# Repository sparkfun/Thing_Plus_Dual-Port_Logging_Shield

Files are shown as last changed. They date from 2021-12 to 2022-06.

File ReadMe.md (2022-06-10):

SparkFun Thing Plus Dual-Port Logging Shield
========================================

SparkFun Thing Plus Dual-Port Logging Shield (DEV-19217) (https://www.sparkfun.com/products/19217)

[*SparkFun Thing Plus Dual-Port Logging Shield (DEV-19217)*](https://www.sparkfun.com/products/19217)

The SparkFun Thing Plus Dual-Port Logging Shield is a Thing Plus/Feather compatible board that allows you to access your microSD card over **_both_** SPI and USB-C! It is designed to be mounted on or under one of our [Thing Plus boards](https://www.sparkfun.com/thing_plus). You can log data to and read data from your microSD card over SPI as usual, using your favorite Arduino SD library. But you can also connect it to your computer via USB-C and read and write files at **_up to 35 MBytes/second_**! The write speed is card-dependent but, in our tests, we've routinely seen write speeds around 20MB/s.

Repository Contents
-------------------

* **/Documents** - Data sheets, additional product information
* **/Firmware/Dual-Port_microSD_Shield** - Firmware for the ATtiny 
* **/Hardware** - Eagle design files (.brd, .sch)
* **/img** - Final production files.

Documentation
--------------
* **[Library](https://github.com/sparkfun/SparkFun_Dual-Port_Logging_Shield_Arduino_Library)** - Arduino library for the SparkFun Thing Plus Dual-Port Logging Shield.
* **[Hookup Guide](https://learn.sparkfun.com/tutorials/thing-plus-dual-port-logging-shield-hookup-guide)** - Basic hookup guide for the SparkFun Thing Plus Dual-Port Logging Shield.

License Information
-------------------

This product is _**open source**_! 

Please review the LICENSE.md file for license information. 

If you have any questions or concerns on licensing, please contact technical support on our [SparkFun forums](https://forum.sparkfun.com/viewforum.php?f=152).

Distributed as-is; no warranty is given.

- Your friends at SparkFun.

_<COLLABORATION CREDIT>_

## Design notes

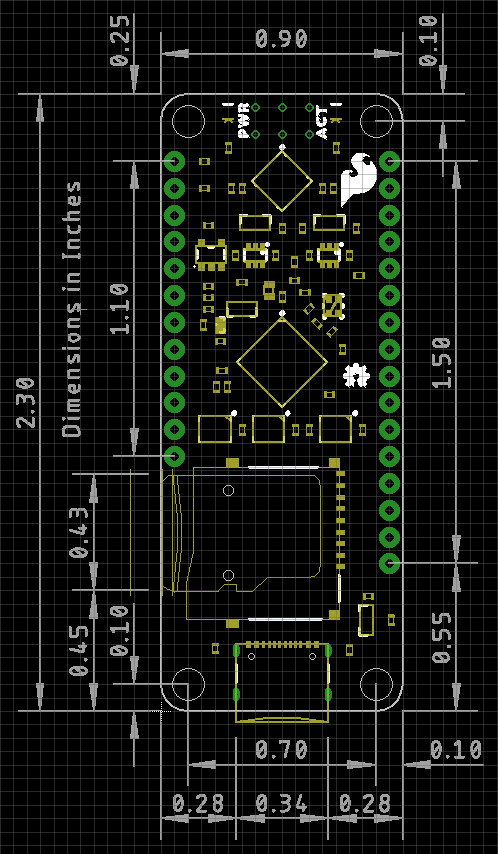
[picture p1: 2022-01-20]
img/Dimensions.png

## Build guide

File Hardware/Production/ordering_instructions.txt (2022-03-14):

panel size, 131x201mm
PCB thickness, 1.6mm
number of layers, 4
soldermask color, Red
silkscreen color, White
oz copper, 1oz
finish, HASL lead free
stencils, top
pcs per panel, 15
min trace width, 0.1524mm / 0.0060in
min drill size, 0.3000mm / 0.0118in
filename to layer stackup 1/2/3/4: GTL, GL2, GL3, GBL

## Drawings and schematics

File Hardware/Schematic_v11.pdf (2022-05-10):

Design by: USB⁻C S | D G S | D G | DS G | D | S G | D | S G

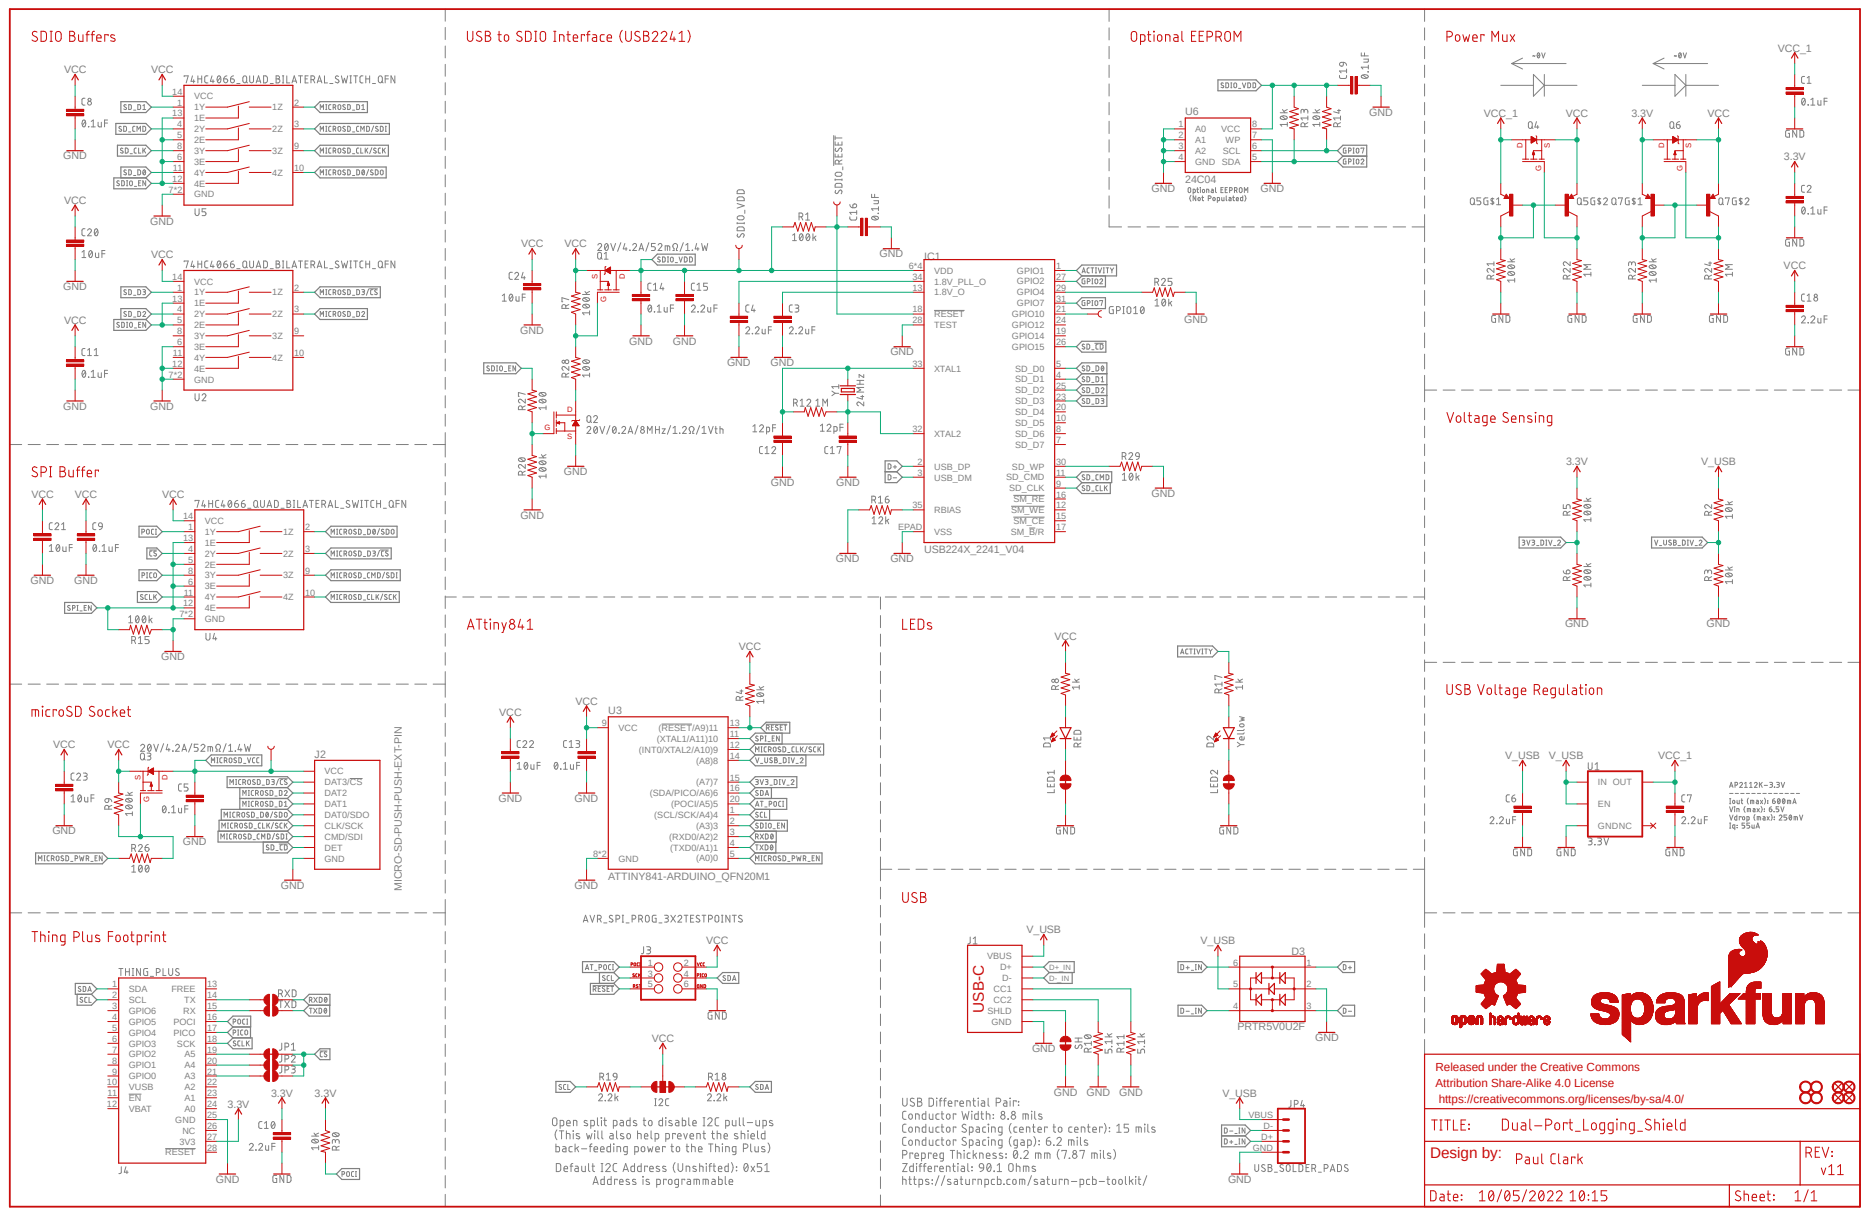
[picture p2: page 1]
GND; GND GND; V_USB; GND MICRO⁻SD⁻PUSH⁻PUSH⁻EXT⁻PIN; ATTINY841-ARDUINO_QFN20M1 GND; V_USB V_USB; VCC; VCC_1; USB224X_2241_V04; PRTR5V0U2F; VBUS CC1 D+D- CC2 SHLD; VCC 9; (A3)3 2 (RXD0/A2)2 3 (TXD0/A1)1 4 (A0)0 5; (SCL/SCK/A4)4 1; (XTAL1/A11)10 11 (INT0/XTAL2/A10)9 12 (A8)8 14; (RESET/A9)11 13 GND 8*2U3; 4Z 10 VCC 14 GND 7*2; 6 SDA 1 SCL 2 GPIO6 3 GPIO5 4 GPIO4 5 GPIO3 6 GPIO2 7 GPIO1 8 GPIO0 9 VUSB 10 EN 11 VBAT 12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

DAT2 DAT1 CLK/SCK DET VCC
DAT3/CS CMD/SDI DAT0/SDO

(POCI/A5)5 20 (SDA/PICO/A6)6 16 (A7)7 15

Released under the Creative Commons
Attribution Share-Alike 4.0 License
https://creativecommons.org/licenses/by-sa/4.0/

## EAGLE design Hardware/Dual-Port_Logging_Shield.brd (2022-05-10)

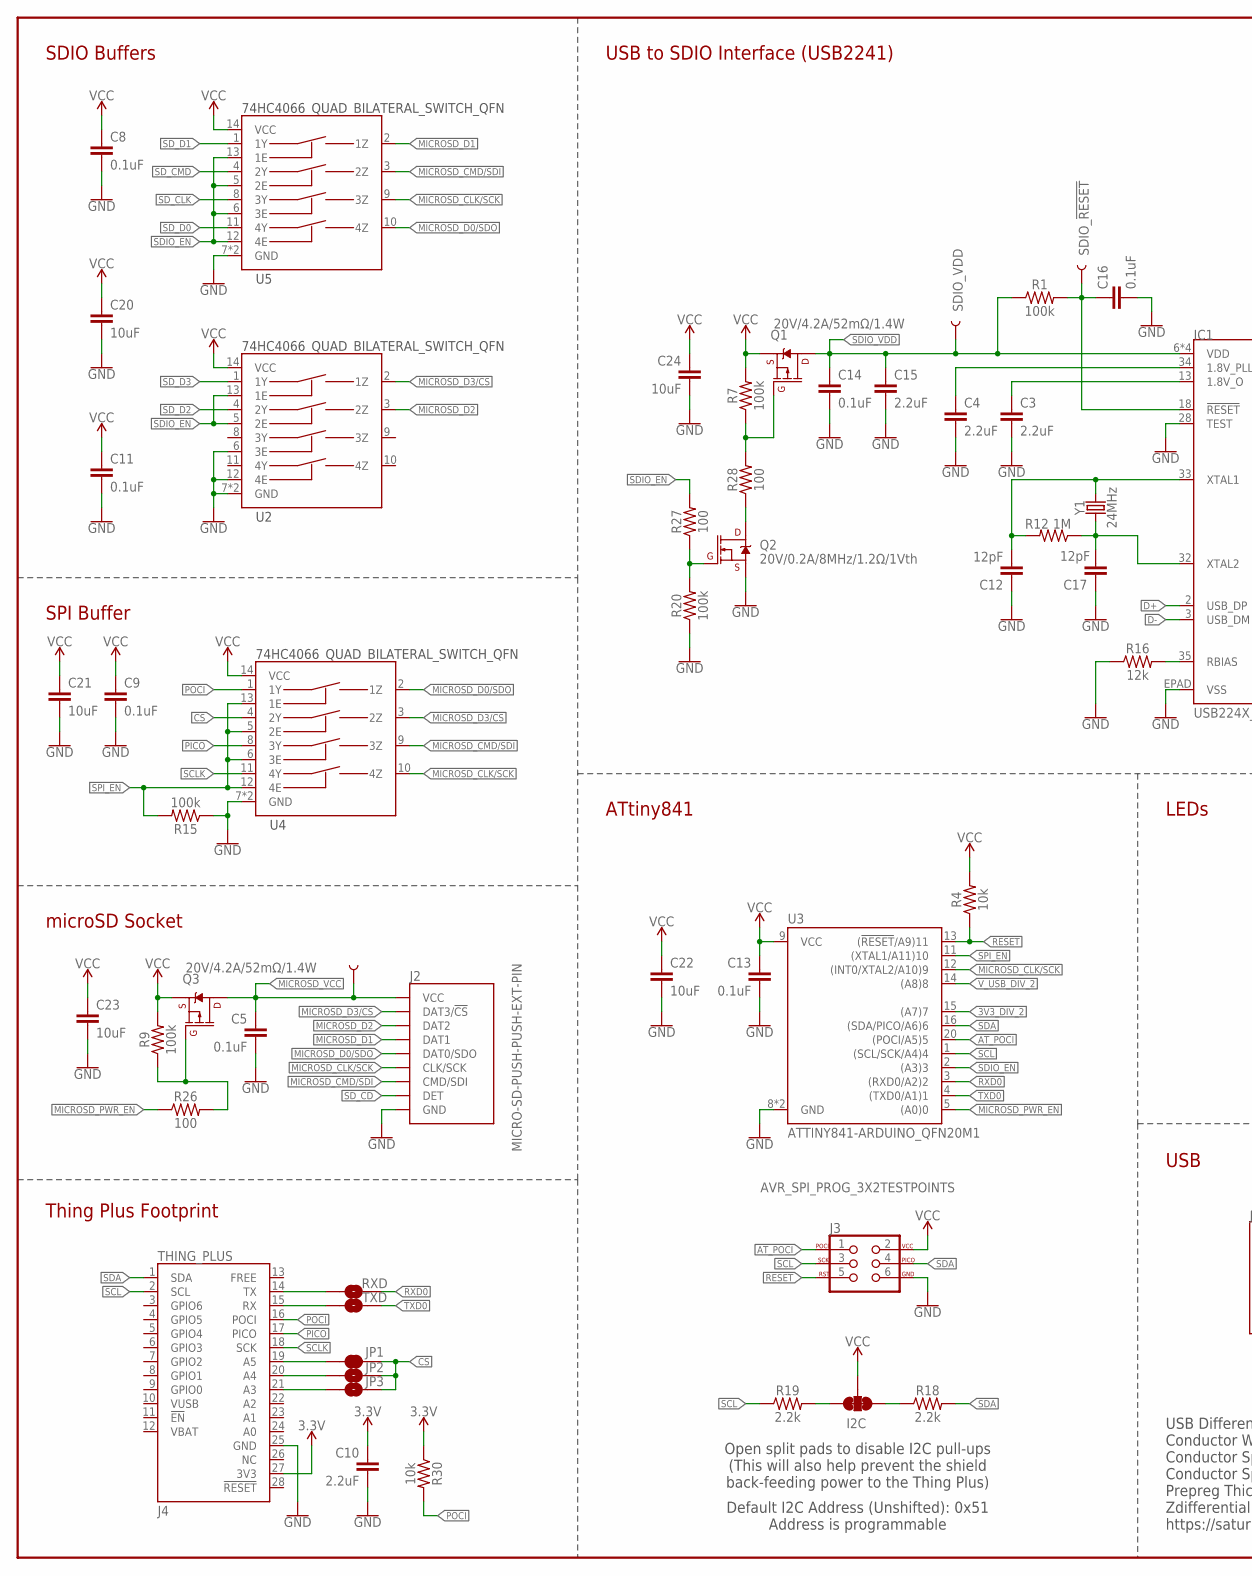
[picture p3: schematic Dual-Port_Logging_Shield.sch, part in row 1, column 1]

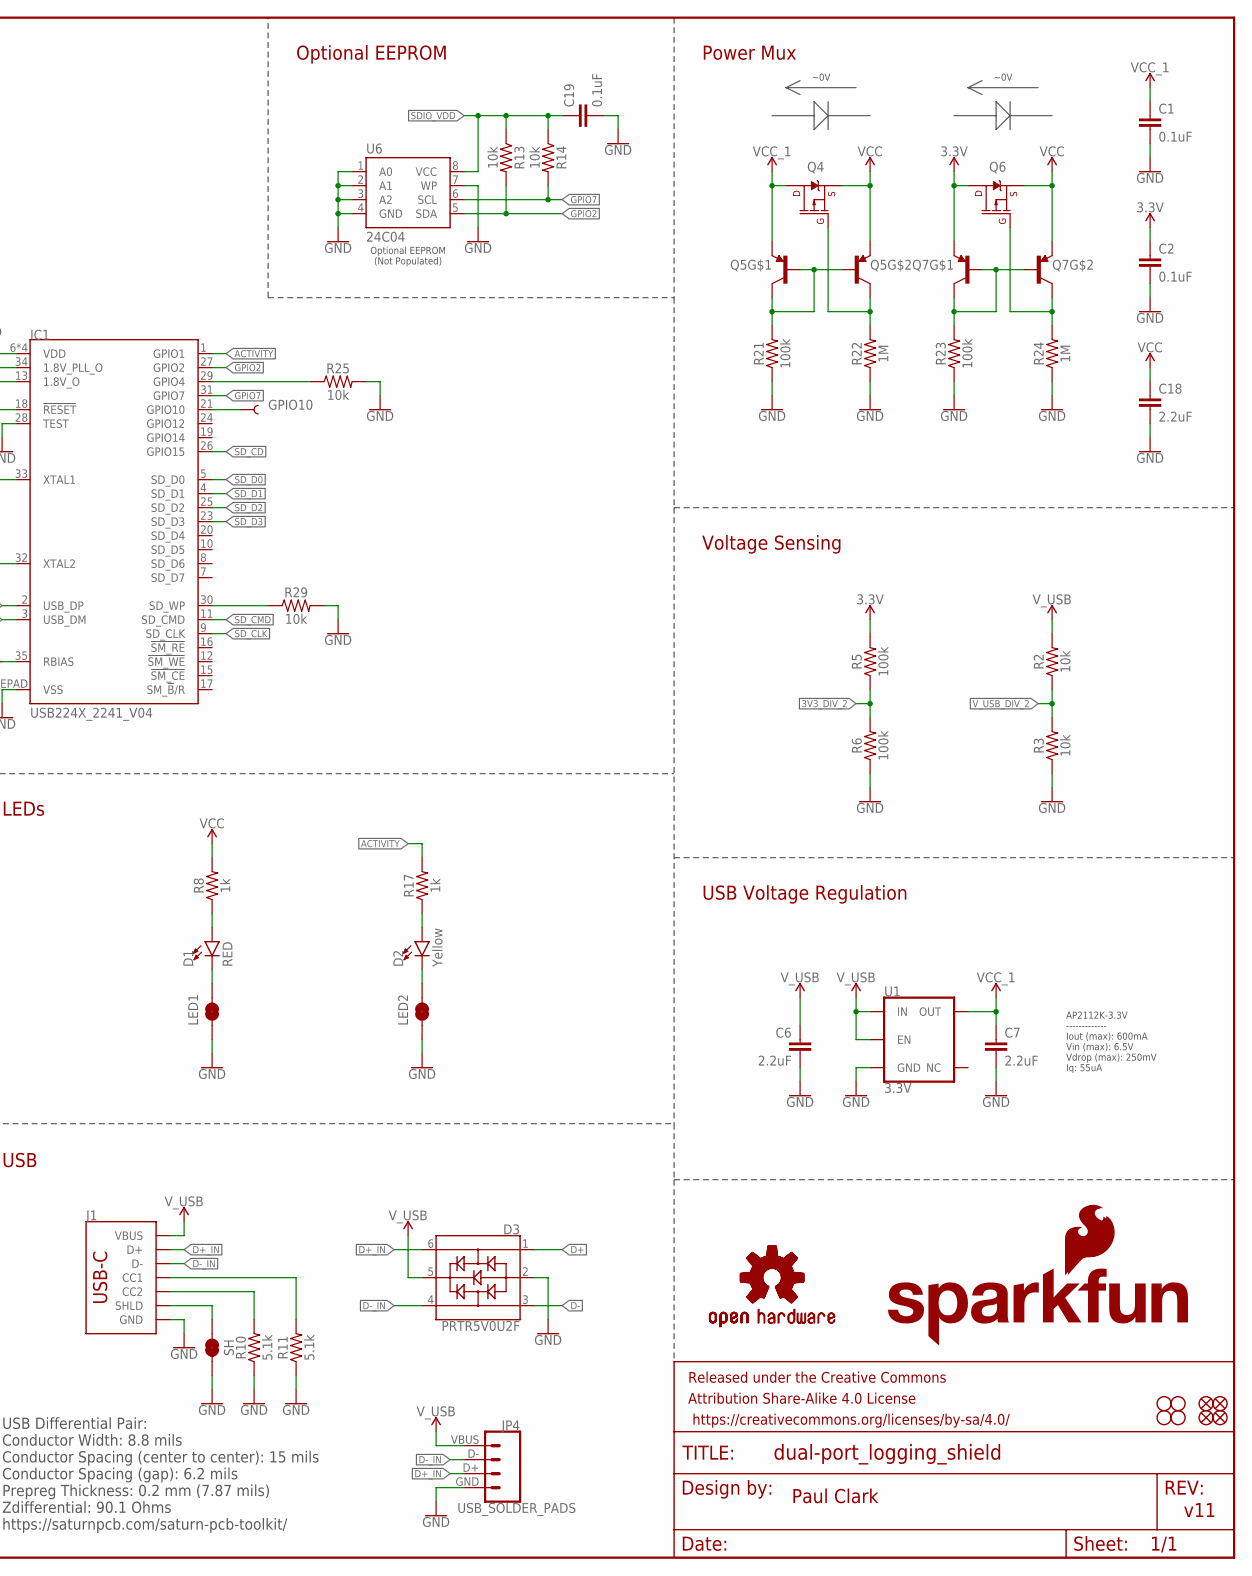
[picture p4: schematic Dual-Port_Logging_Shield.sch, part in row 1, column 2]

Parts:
C1, C2, C5, C8, C9, C11, C13, C14, C16, C19: 0.1uF; 0402-TIGHT
C3, C4, C6, C7, C10, C15, C18: 2.2uF; 0402-TIGHT
C12, C17: 12pF; 0402-TIGHT
C20, C21, C22, C23, C24: 10uF; 0402-TIGHT
D1: RED; LED-0603
D2: Yellow; LED-0603
D3: PRTR5V0U2F; SOT886
FD1, FD2, FD3, FD4: FIDUCIALUFIDUCIAL; FIDUCIAL-MICRO
FRAME1: FRAME-LEDGER; CREATIVE_COMMONS
GPIO10: TEST-POINT3; PAD.03X.03
H1, H2, H3, H4: STAND-OFF
I2C: JUMPER-SMT_3_2-NC_TRACE_SILK; SMT-JUMPER_3_2-NC_TRACE_SILK
IC1: USB224X_2241_V04; 36-QFN
J1: USB_C_4-LAYER_PADS; USB-C-16P_4LAYER-PADS
J2: MICRO-SD-PUSH-PUSH-EXT-PIN; MICROSD-EXTERNALPIN
J3: AVR_SPI_PROG_3X2TESTPOINTS; 2X3_TEST_POINTS
J4: THING_PLUS
JP1: JUMPER-SMT_2_NC_TRACE_SILK; SMT-JUMPER_2_NC_TRACE_SILK
JP2, JP3: JUMPER-SMT_2_NO_SILK; SMT-JUMPER_2_NO_SILK
JP4: USB_SOLDER_PADS; USB-SOLDER-PADS
LED1, LED2: JUMPER-SMT_2_NC_TRACE_SILK; SMT-JUMPER_2_NC_TRACE_SILK
LOGO2, LOGO3: OSHW-LOGOMINI; OSHW-LOGO-MINI
LOGO4: SFE_LOGO_FLAME.2_INCH; SFE_LOGO_FLAME_.2
LOGO5: SFE_LOGO_NAME_FLAME.1_INCH; SFE_LOGO_NAME_FLAME_.1
MICROSD_VCC: TEST-POINT3; PAD.03X.03
Q1, Q3, Q4, Q6: 20V/4.2A/52mΩ/1.4W; SOT23-3
Q2: 20V/0.2A/8MHz/1.2Ω/1Vth; SOT-416FL
Q5, Q7: TRANS_PNP_DUALSOT-363; SOT363_PHILIPS
R1, R5, R6, R7, R9, R15, R20, R21, R23: 100k; 0402-TIGHT
R2, R3, R4, R13, R14, R25, R29, R30: 10k; 0402-TIGHT
R8, R17: 1k; 0402-TIGHT
R10, R11: 5.1k; 0402-TIGHT
R12, R22, R24: 1M; 0402-TIGHT
R16: 12k; 0603
R18, R19: 2.2k; 0402-TIGHT
R26, R27, R28: 100; 0402-TIGHT
RXD: JUMPER-SMT_2_NO_SILK; SMT-JUMPER_2_NO_SILK
SDIO_!RESET!: TEST-POINT3; PAD.03X.03
SDIO_VDD: TEST-POINT3; PAD.03X.03
SH: JUMPER-SMT_2_NC_TRACE_NO-SILK; SMT-JUMPER_2_NC_TRACE_NO-SILK
TXD: JUMPER-SMT_2_NO_SILK; SMT-JUMPER_2_NO_SILK
U1: 3.3V; SOT23-5
U2, U4, U5: 74HC4066_QUAD_BILATERAL_SWITCH_QFN; 14-QFN
U3: ATTINY841-ARDUINO_QFN20M1; QFN20_20M1
U6: 24C04; SO08
Y1: 24MHz; CRYSTAL-SMD-2.0X1.6MM

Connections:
3.3V: C2.1, C10.1, J4.27 (3V3), Q6.3 (D), Q7.1 (E), R5.2, R30.1
3V3_DIV_2: R5.1, R6.2, U3.15 ((A7)7)
!CS!: JP1.2, JP2.2, JP3.2, U4.4 (2Y)
!RESET!: J3.5, R4.1, U3.13 ((!RESET!/A9)11)
ACTIVITY: IC1.1 (GPIO1), R17.2
AT_POCI: J3.1, U3.20 ((POCI/A5)5)
D+: D3.1, IC1.2 (USB_DP)
D+_IN: D3.6, J1.A6 (D+), J1.B6 (D+), JP4.D+ (3)
D-: D3.3, IC1.3 (USB_DM)
D-_IN: D3.4, J1.A7 (D-), J1.B7 (D-), JP4.D- (2)
GND: C1.2, C2.2, C3.2, C4.2, C5.2, C6.2, C7.2, C8.2, C9.2, C10.2, C11.2, C12.1, C13.2, C14.2, C15.2, C16.2, C17.1, C18.2, C19.2, C20.2, C21.2, C22.2, C23.2, C24.2, D3.2, IC1.28 (TEST), IC1.EPAD (VSS), J1.GND, J1.GND2 (GND), J2.6 (GND), J2.10 (GND), J2.11 (GND), J2.12 (GND), J2.13 (GND), J3.6, J4.25 (GND), JP4.GND (4), LED1.1, LED2.1, Q2.2 (S), R3.1, R6.1, R10.1, R11.1, R15.1, R16.1, R20.1, R21.1, R22.1, R23.1, R24.1, R25.2, R29.2, SH.2, U1.2 (GND), U2.6 (3E), U2.7 (GND), U2.12 (4E), U2.EPAD (GND), U3.8 (GND), U3.PAD (GND), U4.7 (GND), U4.EPAD (GND), U5.7 (GND), U5.EPAD (GND), U6.1 (A0), U6.2 (A1), U6.3 (A2), U6.4 (GND), U6.7 (WP)
GPIO2: IC1.27 (GPIO2), R13.2, U6.5 (SDA)
GPIO4: IC1.29 (GPIO4), R25.1
GPIO7: IC1.31 (GPIO7), R14.2, U6.6 (SCL)
GPIO10: GPIO10.1, IC1.21 (GPIO10)
MICROSD_CLK/SCK: J2.5 (CLK/SCK), U3.12 ((INT0/XTAL2/A10)9), U4.10 (4Z), U5.9 (3Z)
MICROSD_CMD/SDI: J2.3 (CMD/SDI), U4.9 (3Z), U5.3 (2Z)
MICROSD_D0/SDO: J2.7 (DAT0/SDO), U4.2 (1Z), U5.10 (4Z)
MICROSD_D1: J2.8 (DAT1), U5.2 (1Z)
MICROSD_D2: J2.1 (DAT2), U2.3 (2Z)
MICROSD_D3/!CS!: J2.2 (DAT3/!CS!), U2.2 (1Z), U4.3 (2Z)
MICROSD_PWR_EN: R26.1, U3.5 ((A0)0)
MICROSD_VCC: C5.1, J2.4 (VCC), MICROSD_VCC.1, Q3.3 (D)
unnamed: J1.A5 (CC1), R11.2
unnamed: J1.B5 (CC2), R10.2
unnamed: C3.1, IC1.13 (1.8V_O)
unnamed: C4.1, IC1.34 (1.8V_PLL_O)
unnamed: Q5.2 (B), Q5.5 (B), Q5.6 (C), R21.2
unnamed: Q3.1 (G), R9.1, R26.2
unnamed: Q2.1 (G), R20.2, R27.1
unnamed: Q2.3 (D), R28.1
unnamed: J4.19 (A5), JP1.1
unnamed: J4.20 (A4), JP2.1
unnamed: J4.21 (A3), JP3.1
unnamed: J1.SHLD1 (SHLD), J1.SHLD2 (SHLD), J1.SHLD3 (SHLD), J1.SHLD4 (SHLD), SH.1
unnamed: Q4.1 (G), Q5.3 (C), R22.2
unnamed: I2C.3, R19.2
unnamed: Q7.2 (B), Q7.5 (B), Q7.6 (C), R23.2
unnamed: I2C.1, R18.1
unnamed: Q1.1 (G), R7.1, R28.2
unnamed: D2.A, R17.1
unnamed: D2.C, LED2.2
unnamed: IC1.30 (SD_WP), R29.1
unnamed: D1.A, R8.1
unnamed: IC1.35 (RBIAS), R16.2
unnamed: J4.14 (TX), RXD.1
unnamed: J4.15 (RX), TXD.1
unnamed: D1.C, LED1.2
unnamed: Q6.1 (G), Q7.3 (C), R24.2
PICO: J4.17 (PICO), U4.8 (3Y)
POCI: J4.16 (POCI), R30.2, U4.1 (1Y)
RXD0: RXD.2, U3.3 ((RXD0/A2)2)
SCL: J3.3, J4.2 (SCL), R19.1, U3.1 ((SCL/SCK/A4)4)
SCLK: J4.18 (SCK), U4.11 (4Y)
SDA: J3.4, J4.1 (SDA), R18.2, U3.16 ((SDA/PICO/A6)6)
SDIO_!RESET!: C16.1, IC1.18 (!RESET!), R1.2, SDIO_!RESET!.1
SDIO_EN: R27.2, U2.5 (2E), U2.13 (1E), U3.2 ((A3)3), U5.5 (2E), U5.6 (3E), U5.12 (4E), U5.13 (1E)
SDIO_VDD: C14.1, C15.1, C19.1, IC1.6 (VDD), IC1.14 (VDD), IC1.22 (VDD), IC1.36 (VDD), Q1.3 (D), R1.1, R13.1, R14.1, SDIO_VDD.1, U6.8 (VCC)
SD_!CD!: IC1.26 (GPIO15), J2.9 (DET)
SD_CLK: IC1.9 (SD_CLK), U5.8 (3Y)
SD_CMD: IC1.11 (SD_CMD), U5.4 (2Y)
SD_D0: IC1.5 (SD_D0), U5.11 (4Y)
SD_D1: IC1.4 (SD_D1), U5.1 (1Y)
SD_D2: IC1.25 (SD_D2), U2.4 (2Y)
SD_D3: IC1.23 (SD_D3), U2.1 (1Y)
SPI_EN: R15.2, U3.11 ((XTAL1/A11)10), U4.5 (2E), U4.6 (3E), U4.12 (4E), U4.13 (1E)
TXD0: TXD.2, U3.4 ((TXD0/A1)1)
VCC: C8.1, C9.1, C11.1, C13.1, C18.1, C20.1, C21.1, C22.1, C23.1, C24.1, I2C.2, J3.2, Q1.2 (S), Q3.2 (S), Q4.2 (S), Q5.4 (E), Q6.2 (S), Q7.4 (E), R4.2, R7.2, R8.2, R9.2, U2.14 (VCC), U3.9 (VCC), U4.14 (VCC), U5.14 (VCC)
VCC_1: C1.1, C7.1, Q4.3 (D), Q5.1 (E), U1.5 (OUT)
V_USB: C6.1, D3.5, J1.VBUS1 (VBUS), J1.VBUS2 (VBUS), JP4.VBUS (1), R2.2, U1.1 (IN), U1.3 (EN)
V_USB_DIV_2: R2.1, R3.2, U3.14 ((A8)8)
XTAL1: C12.2, IC1.33 (XTAL1), R12.2, Y1.3 (2)
XTAL2: C17.2, IC1.32 (XTAL2), R12.1, Y1.1

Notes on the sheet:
Paul Clark
v11
Thing Plus Footprint
Voltage Sensing
USB to SDIO Interface (USB2241)
microSD Socket
SDIO Buffers
Power Mux
USB
USB Voltage Regulation
SPI Buffer
ATtiny841
AP2112K-3.3V ------------- Iout (max): 600mA Vin (max): 6.5V Vdrop (max): 250mV Iq: 55uA
LEDs
Open split pads to disable I2C pull-ups (This will also help prevent the shield back-feeding power to the Thing Plus)
~0V
Optional EEPROM (Not Populated)
Optional EEPROM
Default I2C Address (Unshifted): 0x51 Address is programmable
USB Differential Pair: Conductor Width: 8.8 mils Conductor Spacing (center to center): 15 mils Conductor Spacing (gap): 6.2 mils Prepreg Thickness: 0.2 mm (7.87 mils) Zdifferential: 90.1 Ohms https://saturnpcb.com/saturn-pcb-toolkit/

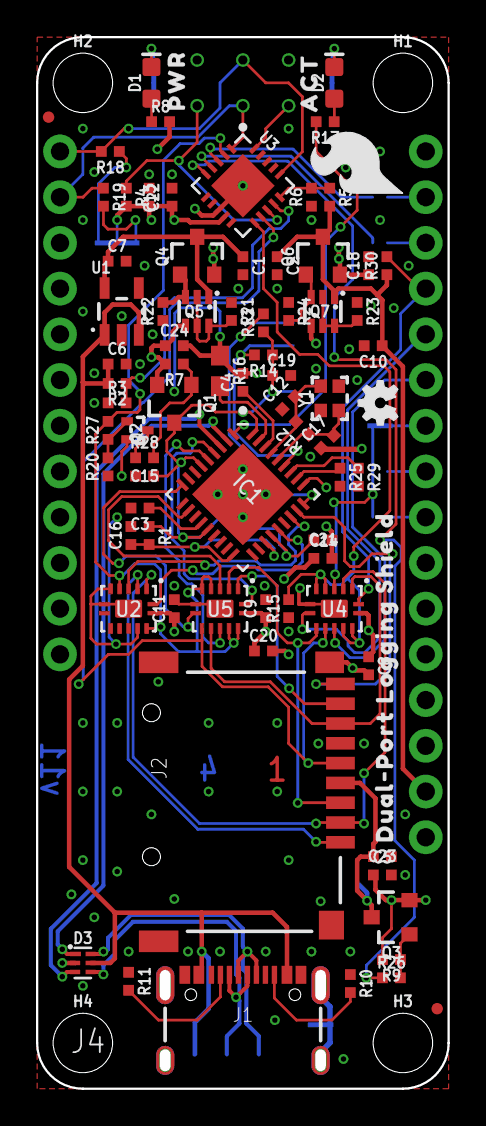
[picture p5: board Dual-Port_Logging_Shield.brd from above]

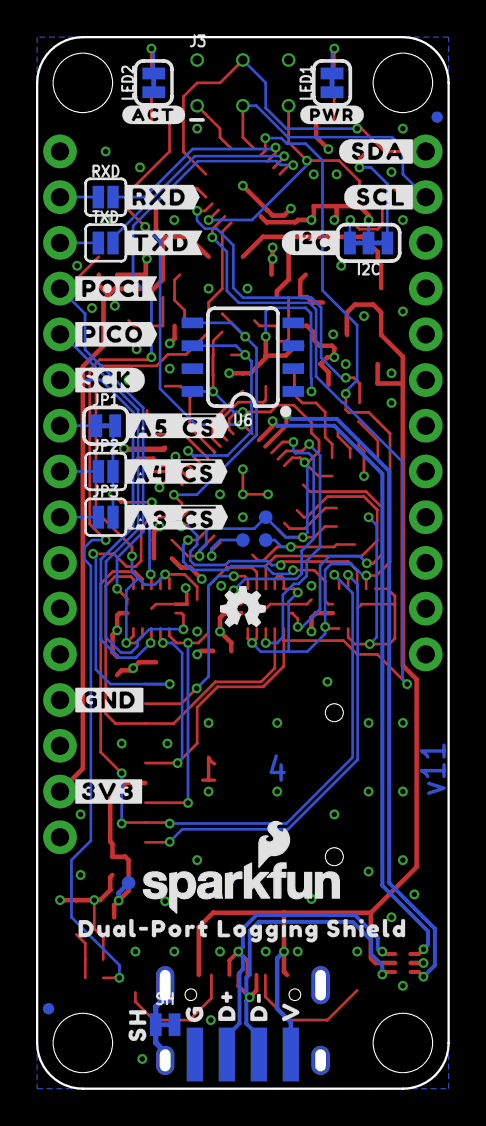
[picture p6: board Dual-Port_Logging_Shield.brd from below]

Board: 4 copper layers, 22.9 x 58.4 mm, 128 parts (41 on the bottom side), 73 nets.

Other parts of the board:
LOGO1: SPECIAL_INSTRUCTIONS-ORDERING; ORDERING_INSTRUCTIONS
U$1: #SDA#0
U$2: #SCL#1
U$3: #POCI#0
U$4: #PICO#1
U$5: #SCK#2
U$6, U$14: DUAL#PORT_LOGGING_SHIELD0
U$7: #GND#0
U$8: #3V3#1
U$9: #RXD#0
U$10: #TXD#1
U$11: PWR0
U$12: ACT0
U$13: #I�C#0
U$15: #PWR#0
U$16: #ACT#0
U$17: #A5__#CS##0
U$18: #A4__#CS##6
U$19: #A3__#CS##6
U$20: SH0
U$21: G0
U$22: V0
U$23: D#0
U$25: D#1

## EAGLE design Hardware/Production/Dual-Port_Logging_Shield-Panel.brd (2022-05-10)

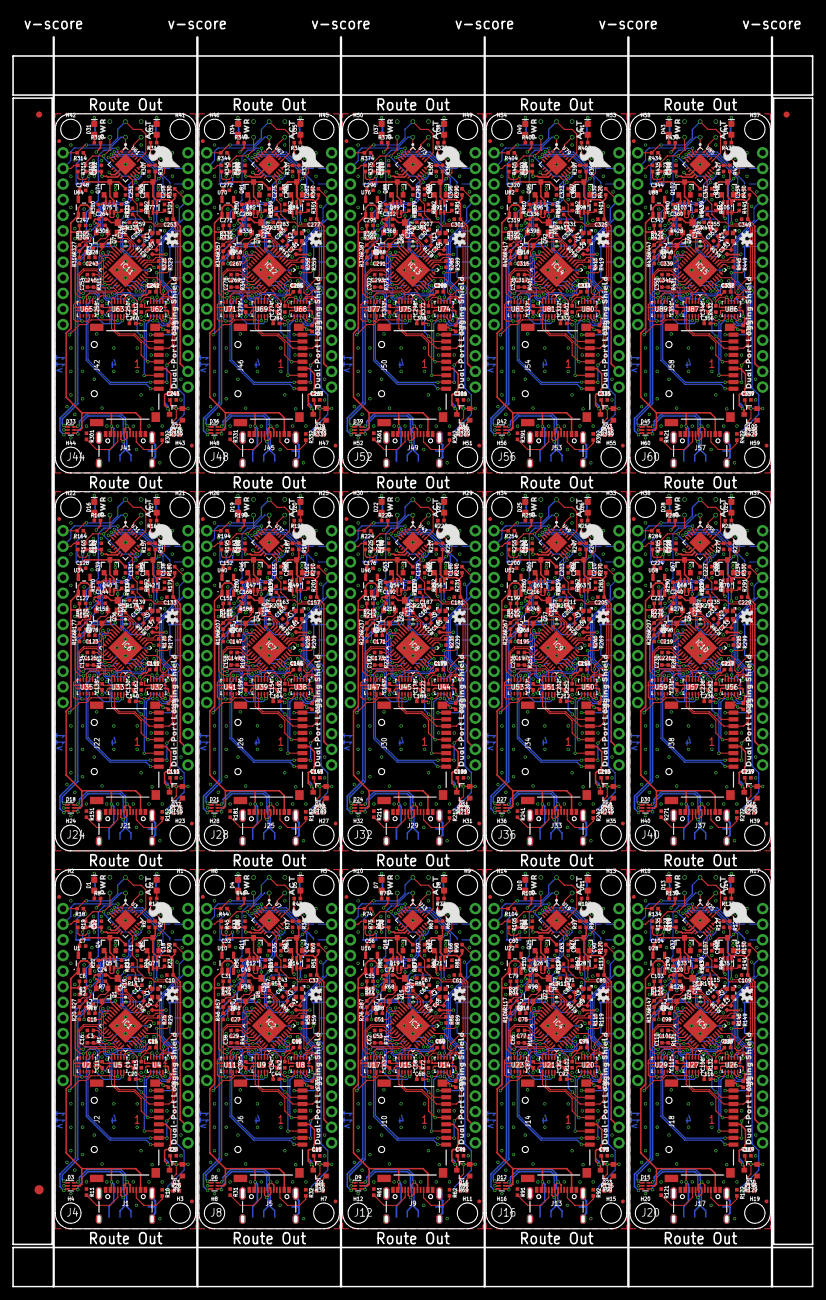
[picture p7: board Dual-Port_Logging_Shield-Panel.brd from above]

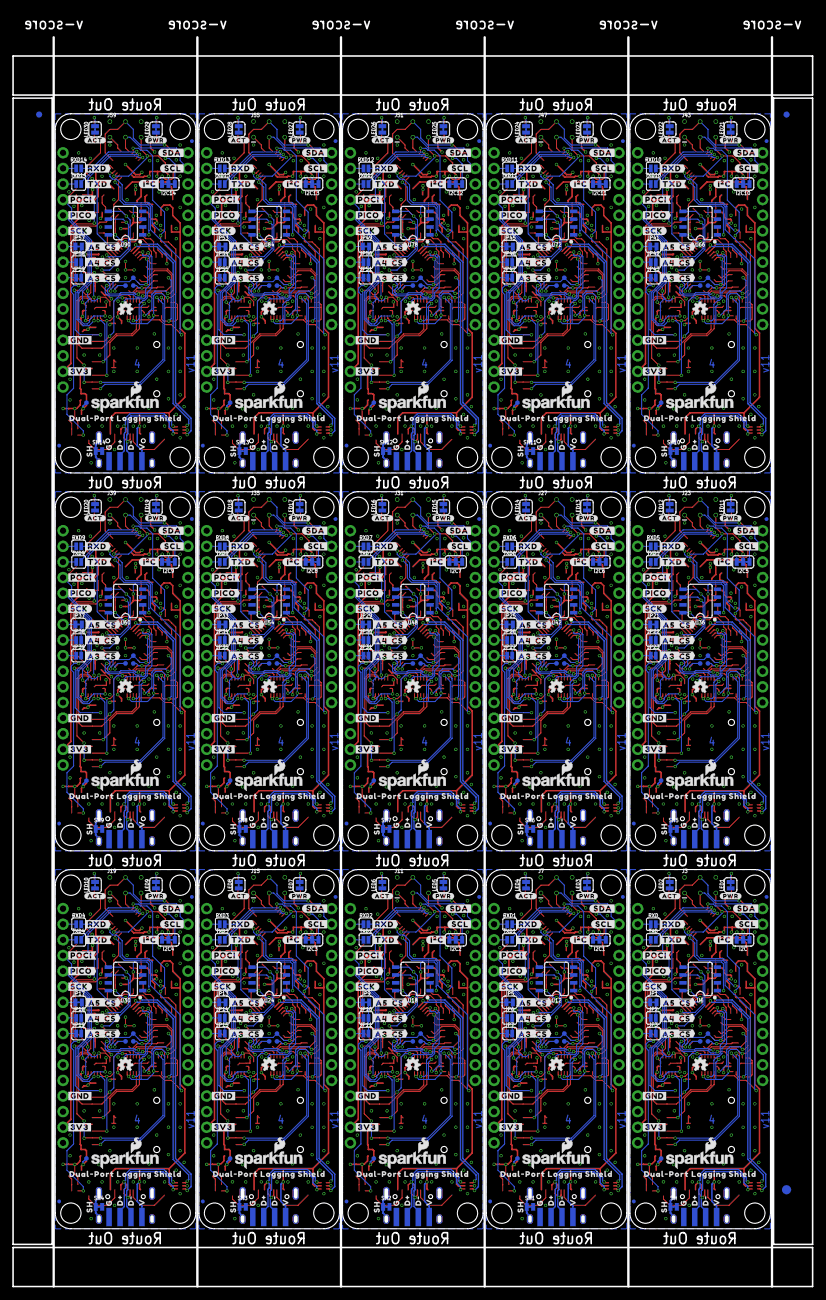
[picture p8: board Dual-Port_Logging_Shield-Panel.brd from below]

Board: 4 copper layers, 130.0 x 203.2 mm, 1896 parts (618 on the bottom side), 1095 nets.

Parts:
C1, C2, C5, C8, C9, C11, C13, C14, C16, C19, C25, C26, C28, C33, C34, C35, C36, C38, C39, C43, C49, C50, C52, C57, C58, C59, C60, C62, C63, C67, C73, C74, C76, C81, C82, C83, C84, C86, C87, C91, C97, C98, C100, C105, C106, C107, C108, C110, C111, C115, C121, C122, C124, C129, C130, C131, C132, C134, C135, C139, C145, C146, C148, C153, C154, C155, C156, C158, C159, C163, C169, C170, C172, C177, C178, C179, C180, C182, C183, C187, C193, C194, C196, C201, C202, C203, C204, C206, C207, C211, C217, C218, C220, C225, C226, C227, C228, C230, C231, C235, C241, C242, C244, C249, C250, C251, C252, C254, C255, C259, C265, C266, C268, C273, C274, C275, C276, C278, C279, C283, C289, C290, C292, C297, C298, C299, C300, C302, C303, C307, C313, C314, C316, C321, C322, C323, C324, C326, C327, C331, C337, C338, C340, C345, C346, C347, C348, C350, C351, C355: 0.1uF; 0402-TIGHT
C3, C4, C6, C7, C10, C15, C18, C27, C29, C30, C31, C32, C37, C42, C51, C53, C54, C55, C56, C61, C66, C75, C77, C78, C79, C80, C85, C90, C99, C101, C102, C103, C104, C109, C114, C123, C125, C126, C127, C128, C133, C138, C147, C149, C150, C151, C152, C157, C162, C171, C173, C174, C175, C176, C181, C186, C195, C197, C198, C199, C200, C205, C210, C219, C221, C222, C223, C224, C229, C234, C243, C245, C246, C247, C248, C253, C258, C267, C269, C270, C271, C272, C277, C282, C291, C293, C294, C295, C296, C301, C306, C315, C317, C318, C319, C320, C325, C330, C339, C341, C342, C343, C344, C349, C354: 2.2uF; 0402-TIGHT
C12, C17, C40, C41, C64, C65, C88, C89, C112, C113, C136, C137, C160, C161, C184, C185, C208, C209, C232, C233, C256, C257, C280, C281, C304, C305, C328, C329, C352, C353: 12pF; 0402-TIGHT
C20, C21, C22, C23, C24, C44, C45, C46, C47, C48, C68, C69, C70, C71, C72, C92, C93, C94, C95, C96, C116, C117, C118, C119, C120, C140, C141, C142, C143, C144, C164, C165, C166, C167, C168, C188, C189, C190, C191, C192, C212, C213, C214, C215, C216, C236, C237, C238, C239, C240, C260, C261, C262, C263, C264, C284, C285, C286, C287, C288, C308, C309, C310, C311, C312, C332, C333, C334, C335, C336, C356, C357, C358, C359, C360: 10uF; 0402-TIGHT
D1, D4, D7, D10, D13, D16, D19, D22, D25, D28, D31, D34, D37, D40, D43: RED; LED-0603
D2, D5, D8, D11, D14, D17, D20, D23, D26, D29, D32, D35, D38, D41, D44: Yellow; LED-0603
D3, D6, D9, D12, D15, D18, D21, D24, D27, D30, D33, D36, D39, D42, D45: PRTR5V0U2F; SOT886
E$1, E$2, E$3, E$4: FIDUCIAL-1X2
E$5, E$6: FIDUCIAL-1.5X3
FD1, FD2, FD3, FD4, FD5, FD6, FD7, FD8, FD9, FD10, FD11, FD12, FD13, FD14, FD15, FD16, FD17, FD18, FD19, FD20, FD21, FD22, FD23, FD24, FD25, FD26, FD27, FD28, FD29, FD30, FD31, FD32, FD33, FD34, FD35, FD36, FD37, FD38, FD39, FD40, FD41, FD42, FD43, FD44, FD45, FD46, FD47, FD48, FD49, FD50, FD51, FD52, FD53, FD54, FD55, FD56, FD57, FD58, FD59, FD60: FIDUCIALUFIDUCIAL; FIDUCIAL-MICRO
GPIO1, GPIO2, GPIO3, GPIO4, GPIO5, GPIO6, GPIO7, GPIO8, GPIO9, GPIO10, GPIO11, GPIO12, GPIO13, GPIO14, GPIO15: TEST-POINT3; PAD.03X.03
H1, H2, H3, H4, H5, H6, H7, H8, H9, H10, H11, H12, H13, H14, H15, H16, H17, H18, H19, H20, H21, H22, H23, H24, H25, H26, H27, H28, H29, H30, H31, H32, H33, H34, H35, H36, H37, H38, H39, H40, H41, H42, H43, H44, H45, H46, H47, H48, H49, H50, H51, H52, H53, H54, H55, H56, H57, H58, H59, H60: STAND-OFF
I2C, I2C1, I2C2, I2C3, I2C4, I2C5, I2C6, I2C7, I2C8, I2C9, I2C10, I2C11, I2C12, I2C13, I2C14: JUMPER-SMT_3_2-NC_TRACE_SILK; SMT-JUMPER_3_2-NC_TRACE_SILK
IC1, IC2, IC3, IC4, IC5, IC6, IC7, IC8, IC9, IC10, IC11, IC12, IC13, IC14, IC15: USB224X_2241_V04; 36-QFN
J1, J5, J9, J13, J17, J21, J25, J29, J33, J37, J41, J45, J49, J53, J57: USB-C-16P_4LAYER-PADS
J2, J6, J10, J14, J18, J22, J26, J30, J34, J38, J42, J46, J50, J54, J58: MICRO-SD-PUSH-PUSH-EXT-PIN; MICROSD-EXTERNALPIN
J3, J7, J11, J15, J19, J23, J27, J31, J35, J39, J43, J47, J51, J55, J59: AVR_SPI_PROG_3X2TESTPOINTS; 2X3_TEST_POINTS
J4, J8, J12, J16, J20, J24, J28, J32, J36, J40, J44, J48, J52, J56, J60: THING_PLUS
JP1, JP5, JP9, JP13, JP17, JP21, JP25, JP29, JP33, JP37, JP41, JP45, JP49, JP53, JP57: JUMPER-SMT_2_NC_TRACE_SILK; SMT-JUMPER_2_NC_TRACE_SILK
JP2, JP3, JP6, JP7, JP10, JP11, JP14, JP15, JP18, JP19, JP22, JP23, JP26, JP27, JP30, JP31, JP34, JP35, JP38, JP39, JP42, JP43, JP46, JP47, JP50, JP51, JP54, JP55, JP58, JP59: JUMPER-SMT_2_NO_SILK; SMT-JUMPER_2_NO_SILK
JP4, JP8, JP12, JP16, JP20, JP24, JP28, JP32, JP36, JP40, JP44, JP48, JP52, JP56, JP60: USB_SOLDER_PADS; USB-SOLDER-PADS
LED1, LED2, LED3, LED4, LED5, LED6, LED7, LED8, LED9, LED10, LED11, LED12, LED13, LED14, LED15, LED16, LED17, LED18, LED19, LED20, LED21, LED22, LED23, LED24, LED25, LED26, LED27, LED28, LED29, LED30: JUMPER-SMT_2_NC_TRACE_SILK; SMT-JUMPER_2_NC_TRACE_SILK
LOGO1, LOGO2, LOGO3, LOGO6, LOGO9, LOGO10, LOGO13, LOGO14, LOGO17, LOGO18, LOGO21, LOGO22, LOGO25, LOGO26, LOGO29, LOGO30, LOGO33, LOGO34, LOGO37, LOGO38, LOGO41, LOGO42, LOGO45, LOGO46, LOGO49, LOGO50, LOGO53, LOGO54, LOGO57, LOGO58: OSHW-LOGOMINI; OSHW-LOGO-MINI
LOGO4, LOGO7, LOGO11, LOGO15, LOGO19, LOGO23, LOGO27, LOGO31, LOGO35, LOGO39, LOGO43, LOGO47, LOGO51, LOGO55, LOGO59: SFE_LOGO_FLAME.2_INCH; SFE_LOGO_FLAME_.2
LOGO5, LOGO8, LOGO12, LOGO16, LOGO20, LOGO24, LOGO28, LOGO32, LOGO36, LOGO40, LOGO44, LOGO48, LOGO52, LOGO56, LOGO60: SFE_LOGO_NAME_FLAME.1_INCH; SFE_LOGO_NAME_FLAME_.1
MICROSD_VCC, MICROSD_VCC1, MICROSD_VCC2, MICROSD_VCC3, MICROSD_VCC4, MICROSD_VCC5, MICROSD_VCC6, MICROSD_VCC7, MICROSD_VCC8, MICROSD_VCC9, MICROSD_VCC10, MICROSD_VCC11, MICROSD_VCC12, MICROSD_VCC13, MICROSD_VCC14: TEST-POINT3; PAD.03X.03
Q1, Q3, Q4, Q6, Q8, Q9, Q11, Q13, Q15, Q16, Q18, Q20, Q22, Q23, Q25, Q27, Q29, Q30, Q32, Q34, Q36, Q37, Q39, Q41, Q43, Q44, Q46, Q48, Q50, Q51, Q53, Q55, Q57, Q58, Q60, Q62, Q64, Q65, Q67, Q69, Q71, Q72, Q74, Q76, Q78, Q79, Q81, Q83, Q85, Q86, Q88, Q90, Q92, Q93, Q95, Q97, Q99, Q100, Q102, Q104: 20V/4.2A/52mΩ/1.4W; SOT23-3
Q2, Q10, Q17, Q24, Q31, Q38, Q45, Q52, Q59, Q66, Q73, Q80, Q87, Q94, Q101: 20V/0.2A/8MHz/1.2Ω/1Vth; SOT-416FL
Q5, Q7, Q12, Q14, Q19, Q21, Q26, Q28, Q33, Q35, Q40, Q42, Q47, Q49, Q54, Q56, Q61, Q63, Q68, Q70, Q75, Q77, Q82, Q84, Q89, Q91, Q96, Q98, Q103, Q105: SOT363_PHILIPS
R1, R5, R6, R7, R9, R15, R20, R21, R23, R36, R37, R38, R39, R41, R42, R46, R49, R51, R66, R67, R68, R69, R71, R72, R76, R79, R81, R96, R97, R98, R99, R101, R102, R106, R109, R111, R126, R127, R128, R129, R131, R132, R136, R139, R141, R156, R157, R158, R159, R161, R162, R166, R169, R171, R186, R187, R188, R189, R191, R192, R196, R199, R201, R216, R217, R218, R219, R221, R222, R226, R229, R231, R246, R247, R248, R249, R251, R252, R256, R259, R261, R276, R277, R278, R279, R281, R282, R286, R289, R291, R306, R307, R308, R309, R311, R312, R316, R319, R321, R336, R337, R338, R339, R341, R342, R346, R349, R351, R366, R367, R368, R369, R371, R372, R376, R379, R381, R396, R397, R398, R399, R401, R402, R406, R409, R411, R426, R427, R428, R429, R431, R432, R436, R439, R441: 100k; 0402-TIGHT
R2, R3, R4, R13, R14, R25, R29, R30, R33, R34, R35, R53, R54, R55, R59, R60, R63, R64, R65, R83, R84, R85, R89, R90, R93, R94, R95, R113, R114, R115, R119, R120, R123, R124, R125, R143, R144, R145, R149, R150, R153, R154, R155, R173, R174, R175, R179, R180, R183, R184, R185, R203, R204, R205, R209, R210, R213, R214, R215, R233, R234, R235, R239, R240, R243, R244, R245, R263, R264, R265, R269, R270, R273, R274, R275, R293, R294, R295, R299, R300, R303, R304, R305, R323, R324, R325, R329, R330, R333, R334, R335, R353, R354, R355, R359, R360, R363, R364, R365, R383, R384, R385, R389, R390, R393, R394, R395, R413, R414, R415, R419, R420, R423, R424, R425, R443, R444, R445, R449, R450: 10k; 0402-TIGHT
R8, R17, R40, R43, R70, R73, R100, R103, R130, R133, R160, R163, R190, R193, R220, R223, R250, R253, R280, R283, R310, R313, R340, R343, R370, R373, R400, R403, R430, R433: 1k; 0402-TIGHT
R10, R11, R31, R32, R61, R62, R91, R92, R121, R122, R151, R152, R181, R182, R211, R212, R241, R242, R271, R272, R301, R302, R331, R332, R361, R362, R391, R392, R421, R422: 5.1k; 0402-TIGHT
R12, R22, R24, R48, R50, R52, R78, R80, R82, R108, R110, R112, R138, R140, R142, R168, R170, R172, R198, R200, R202, R228, R230, R232, R258, R260, R262, R288, R290, R292, R318, R320, R322, R348, R350, R352, R378, R380, R382, R408, R410, R412, R438, R440, R442: 1M; 0402-TIGHT
R16, R47, R77, R107, R137, R167, R197, R227, R257, R287, R317, R347, R377, R407, R437: 12k; 0603
R18, R19, R44, R45, R74, R75, R104, R105, R134, R135, R164, R165, R194, R195, R224, R225, R254, R255, R284, R285, R314, R315, R344, R345, R374, R375, R404, R405, R434, R435: 2.2k; 0402-TIGHT
R26, R27, R28, R56, R57, R58, R86, R87, R88, R116, R117, R118, R146, R147, R148, R176, R177, R178, R206, R207, R208, R236, R237, R238, R266, R267, R268, R296, R297, R298, R326, R327, R328, R356, R357, R358, R386, R387, R388, R416, R417, R418, R446, R447, R448: 100; 0402-TIGHT
RXD, RXD1, RXD2, RXD3, RXD4, RXD5, RXD6, RXD7, RXD8, RXD9, RXD10, RXD11, RXD12, RXD13, RXD14: JUMPER-SMT_2_NO_SILK; SMT-JUMPER_2_NO_SILK
SDIO_!RESET!, SDIO_!RESET!1, SDIO_!RESET!2, SDIO_!RESET!3, SDIO_!RESET!4, SDIO_!RESET!5, SDIO_!RESET!6, SDIO_!RESET!7, SDIO_!RESET!8, SDIO_!RESET!9, SDIO_!RESET!10, SDIO_!RESET!11, SDIO_!RESET!12, SDIO_!RESET!13, SDIO_!RESET!14: TEST-POINT3; PAD.03X.03
SDIO_VDD, SDIO_VDD1, SDIO_VDD2, SDIO_VDD3, SDIO_VDD4, SDIO_VDD5, SDIO_VDD6, SDIO_VDD7, SDIO_VDD8, SDIO_VDD9, SDIO_VDD10, SDIO_VDD11, SDIO_VDD12, SDIO_VDD13, SDIO_VDD14: TEST-POINT3; PAD.03X.03
SH, SH1, SH2, SH3, SH4, SH5, SH6, SH7, SH8, SH9, SH10, SH11, SH12, SH13, SH14: JUMPER-SMT_2_NC_TRACE_NO-SILK; SMT-JUMPER_2_NC_TRACE_NO-SILK
TXD, TXD1, TXD2, TXD3, TXD4, TXD5, TXD6, TXD7, TXD8, TXD9, TXD10, TXD11, TXD12, TXD13, TXD14: JUMPER-SMT_2_NO_SILK; SMT-JUMPER_2_NO_SILK
U1, U10, U16, U22, U28, U34, U40, U46, U52, U58, U64, U70, U76, U82, U88: 3.3V; SOT23-5
U2, U4, U5, U8, U9, U11, U14, U15, U17, U20, U21, U23, U26, U27, U29, U32, U33, U35, U38, U39, U41, U44, U45, U47, U50, U51, U53, U56, U57, U59, U62, U63, U65, U68, U69, U71, U74, U75, U77, U80, U81, U83, U86, U87, U89: 74HC4066_QUAD_BILATERAL_SWITCH_QFN; 14-QFN
U3, U7, U13, U19, U25, U31, U37, U43, U49, U55, U61, U67, U73, U79, U85: ATTINY841-ARDUINO_QFN20M1; QFN20_20M1
U6, U12, U18, U24, U30, U36, U42, U48, U54, U60, U66, U72, U78, U84, U90: 24C04; SO08
U$1, U$32, U$56, U$80, U$104, U$128, U$152, U$176, U$200, U$224, U$248, U$272, U$296, U$320, U$344: #SDA#0
U$2, U$33, U$57, U$81, U$105, U$129, U$153, U$177, U$201, U$225, U$249, U$273, U$297, U$321, U$345: #SCL#1
U$3, U$36, U$60, U$84, U$108, U$132, U$156, U$180, U$204, U$228, U$252, U$276, U$300, U$324, U$348: #POCI#0
U$4, U$37, U$61, U$85, U$109, U$133, U$157, U$181, U$205, U$229, U$253, U$277, U$301, U$325, U$349: #PICO#1
U$5, U$38, U$62, U$86, U$110, U$134, U$158, U$182, U$206, U$230, U$254, U$278, U$302, U$326, U$350: #SCK#2
U$6, U$14, U$30, U$31, U$54, U$55, U$78, U$79, U$102, U$103, U$126, U$127, U$150, U$151, U$174, U$175, U$198, U$199, U$222, U$223, U$246, U$247, U$270, U$271, U$294, U$295, U$318, U$319, U$342, U$343: DUAL#PORT_LOGGING_SHIELD0
U$7, U$42, U$66, U$90, U$114, U$138, U$162, U$186, U$210, U$234, U$258, U$282, U$306, U$330, U$354: #GND#0
U$8, U$43, U$67, U$91, U$115, U$139, U$163, U$187, U$211, U$235, U$259, U$283, U$307, U$331, U$355: #3V3#1
U$9, U$34, U$58, U$82, U$106, U$130, U$154, U$178, U$202, U$226, U$250, U$274, U$298, U$322, U$346: #RXD#0
U$10, U$35, U$59, U$83, U$107, U$131, U$155, U$179, U$203, U$227, U$251, U$275, U$299, U$323, U$347: #TXD#1
U$11, U$24, U$49, U$73, U$97, U$121, U$145, U$169, U$193, U$217, U$241, U$265, U$289, U$313, U$337: PWR0
U$12, U$26, U$50, U$74, U$98, U$122, U$146, U$170, U$194, U$218, U$242, U$266, U$290, U$314, U$338: ACT0
U$13, U$27, U$51, U$75, U$99, U$123, U$147, U$171, U$195, U$219, U$243, U$267, U$291, U$315, U$339: #I�C#0
U$15, U$28, U$52, U$76, U$100, U$124, U$148, U$172, U$196, U$220, U$244, U$268, U$292, U$316, U$340: #PWR#0
U$16, U$29, U$53, U$77, U$101, U$125, U$149, U$173, U$197, U$221, U$245, U$269, U$293, U$317, U$341: #ACT#0
U$17, U$39, U$63, U$87, U$111, U$135, U$159, U$183, U$207, U$231, U$255, U$279, U$303, U$327, U$351: #A5__#CS##0
U$18, U$40, U$64, U$88, U$112, U$136, U$160, U$184, U$208, U$232, U$256, U$280, U$304, U$328, U$352: #A4__#CS##6
U$19, U$41, U$65, U$89, U$113, U$137, U$161, U$185, U$209, U$233, U$257, U$281, U$305, U$329, U$353: #A3__#CS##6
U$20, U$48, U$72, U$96, U$120, U$144, U$168, U$192, U$216, U$240, U$264, U$288, U$312, U$336, U$360: SH0
U$21, U$44, U$68, U$92, U$116, U$140, U$164, U$188, U$212, U$236, U$260, U$284, U$308, U$332, U$356: G0
U$22, U$45, U$69, U$93, U$117, U$141, U$165, U$189, U$213, U$237, U$261, U$285, U$309, U$333, U$357: V0
U$23, U$46, U$70, U$94, U$118, U$142, U$166, U$190, U$214, U$238, U$262, U$286, U$310, U$334, U$358: D#0
U$25, U$47, U$71, U$95, U$119, U$143, U$167, U$191, U$215, U$239, U$263, U$287, U$311, U$335, U$359: D#1
Y1, Y2, Y3, Y4, Y5, Y6, Y7, Y8, Y9, Y10, Y11, Y12, Y13, Y14, Y15: 24MHz; CRYSTAL-SMD-2.0X1.6MM

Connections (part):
3.3V: C2.1, C10.1, J4.27, Q6.3, Q7.1, R5.2, R30.1
3.3V1: C36.1, C37.1, J8.27, Q13.3, Q14.1, R36.2, R60.1
3.3V2: C60.1, C61.1, J12.27, Q20.3, Q21.1, R66.2, R90.1
3.3V3: C84.1, C85.1, J16.27, Q27.3, Q28.1, R96.2, R120.1
3.3V4: C108.1, C109.1, J20.27, Q34.3, Q35.1, R126.2, R150.1
3.3V5: C132.1, C133.1, J24.27, Q41.3, Q42.1, R156.2, R180.1
3.3V6: C156.1, C157.1, J28.27, Q48.3, Q49.1, R186.2, R210.1
3.3V7: C180.1, C181.1, J32.27, Q55.3, Q56.1, R216.2, R240.1
3.3V8: C204.1, C205.1, J36.27, Q62.3, Q63.1, R246.2, R270.1
3.3V9: C228.1, C229.1, J40.27, Q69.3, Q70.1, R276.2, R300.1
3.3V10: C252.1, C253.1, J44.27, Q76.3, Q77.1, R306.2, R330.1
3.3V11: C276.1, C277.1, J48.27, Q83.3, Q84.1, R336.2, R360.1
3.3V12: C300.1, C301.1, J52.27, Q90.3, Q91.1, R366.2, R390.1
3.3V13: C324.1, C325.1, J56.27, Q97.3, Q98.1, R396.2, R420.1
3.3V14: C348.1, C349.1, J60.27, Q104.3, Q105.1, R426.2, R450.1
3V3_DIV_1: R36.1, R37.2, U7.15
3V3_DIV_2: R5.1, R6.2, U3.15
3V3_DIV_3: R66.1, R67.2, U13.15
3V3_DIV_4: R96.1, R97.2, U19.15
3V3_DIV_5: R126.1, R127.2, U25.15
3V3_DIV_6: R156.1, R157.2, U31.15
3V3_DIV_7: R186.1, R187.2, U37.15
3V3_DIV_8: R216.1, R217.2, U43.15
3V3_DIV_9: R246.1, R247.2, U49.15
3V3_DIV_10: R276.1, R277.2, U55.15
3V3_DIV_11: R306.1, R307.2, U61.15
3V3_DIV_12: R336.1, R337.2, U67.15
3V3_DIV_13: R366.1, R367.2, U73.15
3V3_DIV_14: R396.1, R397.2, U79.15
3V3_DIV_15: R426.1, R427.2, U85.15
!CS!: JP1.2, JP2.2, JP3.2, U4.4
!CS!1: JP5.2, JP6.2, JP7.2, U8.4
!CS!2: JP9.2, JP10.2, JP11.2, U14.4
!CS!3: JP13.2, JP14.2, JP15.2, U20.4
!CS!4: JP17.2, JP18.2, JP19.2, U26.4
!CS!5: JP21.2, JP22.2, JP23.2, U32.4
!CS!6: JP25.2, JP26.2, JP27.2, U38.4
!CS!7: JP29.2, JP30.2, JP31.2, U44.4
!CS!8: JP33.2, JP34.2, JP35.2, U50.4
!CS!9: JP37.2, JP38.2, JP39.2, U56.4
!CS!10: JP41.2, JP42.2, JP43.2, U62.4
!CS!11: JP45.2, JP46.2, JP47.2, U68.4
!CS!12: JP49.2, JP50.2, JP51.2, U74.4
!CS!13: JP53.2, JP54.2, JP55.2, U80.4
!CS!14: JP57.2, JP58.2, JP59.2, U86.4
!RESET!: J3.5, R4.1, U3.13
!RESET!1: J7.5, R33.1, U7.13
!RESET!2: J11.5, R63.1, U13.13
!RESET!3: J15.5, R93.1, U19.13
!RESET!4: J19.5, R123.1, U25.13
!RESET!5: J23.5, R153.1, U31.13
!RESET!6: J27.5, R183.1, U37.13
!RESET!7: J31.5, R213.1, U43.13
!RESET!8: J35.5, R243.1, U49.13
!RESET!9: J39.5, R273.1, U55.13
!RESET!10: J43.5, R303.1, U61.13
!RESET!11: J47.5, R333.1, U67.13
!RESET!12: J51.5, R363.1, U73.13
!RESET!13: J55.5, R393.1, U79.13
!RESET!14: J59.5, R423.1, U85.13
ACTIVITY: IC1.1, R17.2
ACTIVITY1: IC2.1, R43.2
ACTIVITY2: IC3.1, R73.2
ACTIVITY3: IC4.1, R103.2
ACTIVITY4: IC5.1, R133.2
ACTIVITY5: IC6.1, R163.2
ACTIVITY6: IC7.1, R193.2
ACTIVITY7: IC8.1, R223.2
ACTIVITY8: IC9.1, R253.2
ACTIVITY9: IC10.1, R283.2
ACTIVITY10: IC11.1, R313.2
ACTIVITY11: IC12.1, R343.2
ACTIVITY12: IC13.1, R373.2
ACTIVITY13: IC14.1, R403.2
ACTIVITY14: IC15.1, R433.2
AT_POCI: J3.1, U3.20
AT_POCI1: J7.1, U7.20
AT_POCI2: J11.1, U13.20
AT_POCI3: J15.1, U19.20
AT_POCI4: J19.1, U25.20
AT_POCI5: J23.1, U31.20
AT_POCI6: J27.1, U37.20
AT_POCI7: J31.1, U43.20
AT_POCI8: J35.1, U49.20
AT_POCI9: J39.1, U55.20
AT_POCI10: J43.1, U61.20
AT_POCI11: J47.1, U67.20
AT_POCI12: J51.1, U73.20
AT_POCI13: J55.1, U79.20
AT_POCI14: J59.1, U85.20
D+: D3.1, IC1.2
D+1: D6.1, IC2.2
D+2: D9.1, IC3.2
D+3: D12.1, IC4.2
D+4: D15.1, IC5.2
D+5: D18.1, IC6.2
D+6: D21.1, IC7.2
D+7: D24.1, IC8.2
D+8: D27.1, IC9.2
D+9: D30.1, IC10.2
D+10: D33.1, IC11.2
D+11: D36.1, IC12.2
D+12: D39.1, IC13.2
D+13: D42.1, IC14.2
D+14: D45.1, IC15.2
D+_IN: D3.6, J1.A6, J1.B6, JP4.D+
D+_IN1: D6.6, J5.A6, J5.B6, JP8.D+
D+_IN2: D9.6, J9.A6, J9.B6, JP12.D+
D+_IN3: D12.6, J13.A6, J13.B6, JP16.D+
D+_IN4: D15.6, J17.A6, J17.B6, JP20.D+
D+_IN5: D18.6, J21.A6, J21.B6, JP24.D+
D+_IN6: D21.6, J25.A6, J25.B6, JP28.D+
D+_IN7: D24.6, J29.A6, J29.B6, JP32.D+
D+_IN8: D27.6, J33.A6, J33.B6, JP36.D+
D+_IN9: D30.6, J37.A6, J37.B6, JP40.D+
D+_IN10: D33.6, J41.A6, J41.B6, JP44.D+
D+_IN11: D36.6, J45.A6, J45.B6, JP48.D+
D+_IN12: D39.6, J49.A6, J49.B6, JP52.D+
D+_IN13: D42.6, J53.A6, J53.B6, JP56.D+
D+_IN14: D45.6, J57.A6, J57.B6, JP60.D+
D-: D3.3, IC1.3
D-1: D6.3, IC2.3
D-2: D9.3, IC3.3
D-3: D12.3, IC4.3
D-4: D15.3, IC5.3
D-5: D18.3, IC6.3
D-6: D21.3, IC7.3
D-7: D24.3, IC8.3
D-8: D27.3, IC9.3
D-9: D30.3, IC10.3
D-10: D33.3, IC11.3
D-11: D36.3, IC12.3
D-12: D39.3, IC13.3
D-13: D42.3, IC14.3
D-14: D45.3, IC15.3
D-_IN: D3.4, J1.A7, J1.B7, JP4.D-
D-_IN1: D6.4, J5.A7, J5.B7, JP8.D-
D-_IN2: D9.4, J9.A7, J9.B7, JP12.D-
D-_IN3: D12.4, J13.A7, J13.B7, JP16.D-
D-_IN4: D15.4, J17.A7, J17.B7, JP20.D-
D-_IN5: D18.4, J21.A7, J21.B7, JP24.D-
D-_IN6: D21.4, J25.A7, J25.B7, JP28.D-
D-_IN7: D24.4, J29.A7, J29.B7, JP32.D-
D-_IN8: D27.4, J33.A7, J33.B7, JP36.D-
D-_IN9: D30.4, J37.A7, J37.B7, JP40.D-
D-_IN10: D33.4, J41.A7, J41.B7, JP44.D-
D-_IN11: D36.4, J45.A7, J45.B7, JP48.D-
D-_IN12: D39.4, J49.A7, J49.B7, JP52.D-
D-_IN13: D42.4, J53.A7, J53.B7, JP56.D-
D-_IN14: D45.4, J57.A7, J57.B7, JP60.D-
GND: C1.2, C2.2, C3.2, C4.2, C5.2, C6.2, C7.2, C8.2, C9.2, C10.2, C11.2, C12.1, C13.2, C14.2, C15.2, C16.2, C17.1, C18.2, C19.2, C20.2, C21.2, C22.2, C23.2, C24.2, D3.2, IC1.28, IC1.EPAD, J1.GND, J1.GND2, J2.6, J2.10, J2.11, J2.12, J2.13, J3.6, J4.25, JP4.GND, LED1.1, LED2.1, Q2.2, R3.1, R6.1, R10.1, R11.1, R15.1, R16.1, R20.1, R21.1, R22.1, R23.1, R24.1, R25.2, R29.2, SH.2, U1.2, U2.6, U2.7, U2.12, U2.EPAD, U3.8, U3.PAD, U4.7, U4.EPAD, U5.7, U5.EPAD, U6.1, U6.2, U6.3, U6.4, U6.7
GND1: C25.2, C26.2, C27.2, C28.2, C29.2, C30.2, C31.2, C32.2, C33.2, C34.2, C35.2, C36.2, C37.2, C38.2, C39.2, C40.1, C41.1, C42.2, C43.2, C44.2, C45.2, C46.2, C47.2, C48.2, D6.2, IC2.28, IC2.EPAD, J5.GND, J5.GND2, J6.6, J6.10, J6.11, J6.12, J6.13, J7.6, J8.25, JP8.GND, LED3.1, LED4.1, Q10.2, R31.1, R32.1, R35.1, R37.1, R42.1, R46.1, R47.1, R49.1, R50.1, R51.1, R52.1, R55.2, R59.2, SH1.2, U7.8, U7.PAD, U8.7, U8.EPAD, U9.7, U9.EPAD, U10.2, U11.6, U11.7, U11.12, U11.EPAD, U12.1, U12.2, U12.3, U12.4, U12.7
GND2: C49.2, C50.2, C51.2, C52.2, C53.2, C54.2, C55.2, C56.2, C57.2, C58.2, C59.2, C60.2, C61.2, C62.2, C63.2, C64.1, C65.1, C66.2, C67.2, C68.2, C69.2, C70.2, C71.2, C72.2, D9.2, IC3.28, IC3.EPAD, J9.GND, J9.GND2, J10.6, J10.10, J10.11, J10.12, J10.13, J11.6, J12.25, JP12.GND, LED5.1, LED6.1, Q17.2, R61.1, R62.1, R65.1, R67.1, R72.1, R76.1, R77.1, R79.1, R80.1, R81.1, R82.1, R85.2, R89.2, SH2.2, U13.8, U13.PAD, U14.7, U14.EPAD, U15.7, U15.EPAD, U16.2, U17.6, U17.7, U17.12, U17.EPAD, U18.1, U18.2, U18.3, U18.4, U18.7
GND3: C73.2, C74.2, C75.2, C76.2, C77.2, C78.2, C79.2, C80.2, C81.2, C82.2, C83.2, C84.2, C85.2, C86.2, C87.2, C88.1, C89.1, C90.2, C91.2, C92.2, C93.2, C94.2, C95.2, C96.2, D12.2, IC4.28, IC4.EPAD, J13.GND, J13.GND2, J14.6, J14.10, J14.11, J14.12, J14.13, J15.6, J16.25, JP16.GND, LED7.1, LED8.1, Q24.2, R91.1, R92.1, R95.1, R97.1, R102.1, R106.1, R107.1, R109.1, R110.1, R111.1, R112.1, R115.2, R119.2, SH3.2, U19.8, U19.PAD, U20.7, U20.EPAD, U21.7, U21.EPAD, U22.2, U23.6, U23.7, U23.12, U23.EPAD, U24.1, U24.2, U24.3, U24.4, U24.7
GND4: C97.2, C98.2, C99.2, C100.2, C101.2, C102.2, C103.2, C104.2, C105.2, C106.2, C107.2, C108.2, C109.2, C110.2, C111.2, C112.1, C113.1, C114.2, C115.2, C116.2, C117.2, C118.2, C119.2, C120.2, D15.2, IC5.28, IC5.EPAD, J17.GND, J17.GND2, J18.6, J18.10, J18.11, J18.12, J18.13, J19.6, J20.25, JP20.GND, LED9.1, LED10.1, Q31.2, R121.1, R122.1, R125.1, R127.1, R132.1, R136.1, R137.1, R139.1, R140.1, R141.1, R142.1, R145.2, R149.2, SH4.2, U25.8, U25.PAD, U26.7, U26.EPAD, U27.7, U27.EPAD, U28.2, U29.6, U29.7, U29.12, U29.EPAD, U30.1, U30.2, U30.3, U30.4, U30.7
GND5: C121.2, C122.2, C123.2, C124.2, C125.2, C126.2, C127.2, C128.2, C129.2, C130.2, C131.2, C132.2, C133.2, C134.2, C135.2, C136.1, C137.1, C138.2, C139.2, C140.2, C141.2, C142.2, C143.2, C144.2, D18.2, IC6.28, IC6.EPAD, J21.GND, J21.GND2, J22.6, J22.10, J22.11, J22.12, J22.13, J23.6, J24.25, JP24.GND, LED11.1, LED12.1, Q38.2, R151.1, R152.1, R155.1, R157.1, R162.1, R166.1, R167.1, R169.1, R170.1, R171.1, R172.1, R175.2, R179.2, SH5.2, U31.8, U31.PAD, U32.7, U32.EPAD, U33.7, U33.EPAD, U34.2, U35.6, U35.7, U35.12, U35.EPAD, U36.1, U36.2, U36.3, U36.4, U36.7
GND6: C145.2, C146.2, C147.2, C148.2, C149.2, C150.2, C151.2, C152.2, C153.2, C154.2, C155.2, C156.2, C157.2, C158.2, C159.2, C160.1, C161.1, C162.2, C163.2, C164.2, C165.2, C166.2, C167.2, C168.2, D21.2, IC7.28, IC7.EPAD, J25.GND, J25.GND2, J26.6, J26.10, J26.11, J26.12, J26.13, J27.6, J28.25, JP28.GND, LED13.1, LED14.1, Q45.2, R181.1, R182.1, R185.1, R187.1, R192.1, R196.1, R197.1, R199.1, R200.1, R201.1, R202.1, R205.2, R209.2, SH6.2, U37.8, U37.PAD, U38.7, U38.EPAD, U39.7, U39.EPAD, U40.2, U41.6, U41.7, U41.12, U41.EPAD, U42.1, U42.2, U42.3, U42.4, U42.7
GND7: C169.2, C170.2, C171.2, C172.2, C173.2, C174.2, C175.2, C176.2, C177.2, C178.2, C179.2, C180.2, C181.2, C182.2, C183.2, C184.1, C185.1, C186.2, C187.2, C188.2, C189.2, C190.2, C191.2, C192.2, D24.2, IC8.28, IC8.EPAD, J29.GND, J29.GND2, J30.6, J30.10, J30.11, J30.12, J30.13, J31.6, J32.25, JP32.GND, LED15.1, LED16.1, Q52.2, R211.1, R212.1, R215.1, R217.1, R222.1, R226.1, R227.1, R229.1, R230.1, R231.1, R232.1, R235.2, R239.2, SH7.2, U43.8, U43.PAD, U44.7, U44.EPAD, U45.7, U45.EPAD, U46.2, U47.6, U47.7, U47.12, U47.EPAD, U48.1, U48.2, U48.3, U48.4, U48.7
GND8: C193.2, C194.2, C195.2, C196.2, C197.2, C198.2, C199.2, C200.2, C201.2, C202.2, C203.2, C204.2, C205.2, C206.2, C207.2, C208.1, C209.1, C210.2, C211.2, C212.2, C213.2, C214.2, C215.2, C216.2, D27.2, IC9.28, IC9.EPAD, J33.GND, J33.GND2, J34.6, J34.10, J34.11, J34.12, J34.13, J35.6, J36.25, JP36.GND, LED17.1, LED18.1, Q59.2, R241.1, R242.1, R245.1, R247.1, R252.1, R256.1, R257.1, R259.1, R260.1, R261.1, R262.1, R265.2, R269.2, SH8.2, U49.8, U49.PAD, U50.7, U50.EPAD, U51.7, U51.EPAD, U52.2, U53.6, U53.7, U53.12, U53.EPAD, U54.1, U54.2, U54.3, U54.4, U54.7
GND9: C217.2, C218.2, C219.2, C220.2, C221.2, C222.2, C223.2, C224.2, C225.2, C226.2, C227.2, C228.2, C229.2, C230.2, C231.2, C232.1, C233.1, C234.2, C235.2, C236.2, C237.2, C238.2, C239.2, C240.2, D30.2, IC10.28, IC10.EPAD, J37.GND, J37.GND2, J38.6, J38.10, J38.11, J38.12, J38.13, J39.6, J40.25, JP40.GND, LED19.1, LED20.1, Q66.2, R271.1, R272.1, R275.1, R277.1, R282.1, R286.1, R287.1, R289.1, R290.1, R291.1, R292.1, R295.2, R299.2, SH9.2, U55.8, U55.PAD, U56.7, U56.EPAD, U57.7, U57.EPAD, U58.2, U59.6, U59.7, U59.12, U59.EPAD, U60.1, U60.2, U60.3, U60.4, U60.7
GND10: C241.2, C242.2, C243.2, C244.2, C245.2, C246.2, C247.2, C248.2, C249.2, C250.2, C251.2, C252.2, C253.2, C254.2, C255.2, C256.1, C257.1, C258.2, C259.2, C260.2, C261.2, C262.2, C263.2, C264.2, D33.2, IC11.28, IC11.EPAD, J41.GND, J41.GND2, J42.6, J42.10, J42.11, J42.12, J42.13, J43.6, J44.25, JP44.GND, LED21.1, LED22.1, Q73.2, R301.1, R302.1, R305.1, R307.1, R312.1, R316.1, R317.1, R319.1, R320.1, R321.1, R322.1, R325.2, R329.2, SH10.2, U61.8, U61.PAD, U62.7, U62.EPAD, U63.7, U63.EPAD, U64.2, U65.6, U65.7, U65.12, U65.EPAD, U66.1, U66.2, U66.3, U66.4, U66.7
GND11: C265.2, C266.2, C267.2, C268.2, C269.2, C270.2, C271.2, C272.2, C273.2, C274.2, C275.2, C276.2, C277.2, C278.2, C279.2, C280.1, C281.1, C282.2, C283.2, C284.2, C285.2, C286.2, C287.2, C288.2, D36.2, IC12.28, IC12.EPAD, J45.GND, J45.GND2, J46.6, J46.10, J46.11, J46.12, J46.13, J47.6, J48.25, JP48.GND, LED23.1, LED24.1, Q80.2, R331.1, R332.1, R335.1, R337.1, R342.1, R346.1, R347.1, R349.1, R350.1, R351.1, R352.1, R355.2, R359.2, SH11.2, U67.8, U67.PAD, U68.7, U68.EPAD, U69.7, U69.EPAD, U70.2, U71.6, U71.7, U71.12, U71.EPAD, U72.1, U72.2, U72.3, U72.4, U72.7
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

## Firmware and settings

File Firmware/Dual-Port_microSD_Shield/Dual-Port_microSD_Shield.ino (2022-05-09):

/*
  Dual-Port microSD Shield Firmware
  By: Paul Clark
  Date: May 6th 2022
  Version: 1.1

  This firmware runs on the ATtiny841 on the Dual-Port microSD Shield.

  Uses Spence Konde's ATTinyCore boards:
  https://github.com/SpenceKonde/ATTinyCore
  https://github.com/SpenceKonde/ATTinyCore/blob/master/Installation.md
  Add this URL to the Additional Boards Manager URLs in File\Preferences:
  http://drazzy.com/package_drazzy.com_index.json
  and then use the Boards Manager to add support for the ATtiny: http://boardsmanager/All#ATTinyCore

  The shield's default I2C address is 0x51. The address is stored in eeprom and can be changed.
  See the code example for more details.

  Set Board to ATtiny441/841 (No bootloader)
  Set Chip to ATtiny841
  Set Clock Source to 4MHz (internal, Vcc < 4.5)
  Set Pin Mapping to Clockwise
  Set Wire Mode to Slave Only
  Set millis()/micros() to Enabled
  Set Save EEPROM to EEPROM Not Retained
  Set BOD Level to BOD Enabled 1.8V
  Set BOD Mode (Active) to BOD Enabled
  Set BOD Mode (Sleep) to BOD Enabled

  Fuse byte settings (default to a 1MHz clock, the code will increase the clock to 4MHz):
  Low:  0b01000010 = 0x42 : divide clock by 8, no clock out, slowly rising power, 8MHz internal oscillator
  High: 0b11011110 = 0xDE : reset not disabled, no debug wire, SPI programming enabled, WDT not always on, EEPROM not preserved, BOD 1.8V
  Ext:  0b11110101 = 0xF5 : ULP Osc 32kHz, BOD (Sleep) enabled, BOD (Active) enabled, no self-programming

  Pin Allocation (Physical pins are for the QFN package):
  D0:  Physical Pin 5  (PA0 / A0)          : microSD Power Enable
  D1:  Physical Pin 4  (PA1 / A1/TXD0)     : Serial TXD
  D2:  Physical Pin 3  (PA2 / A2/RXD0)     : Serial RXD
  D3:  Physical Pin 2  (PA3 / A3)          : SDIO (USB2241) Enable
  D4:  Physical Pin 1  (PA4 / A4/SCK/SCL)  : I2C SCL
  D5:  Physical Pin 20 (PA5 / A5/CIPO)     : POCI - connected to pin 1 of the ISP header
  D6:  Physical Pin 16 (PA6 / A6/COPI/SDA) : I2C SDA
  D7:  Physical Pin 15 (PA7 / A7)          : Thing Plus 3V3 divided by 2
  D8:  Physical Pin 14 (PB2 / A8)          : USB 5V divided by 2
  D11: Physical Pin 13 (PB3 / A9/!RESET)   : !RESET
  D9:  Physical Pin 12 (PB1 / A10/INT0)    : microSD SCK (Interrupt 0)
  D10: Physical Pin 11 (PB0 / A11)         : SPI Buffer Enable

  There is a huge amount we could do with this firmware, but we have decided to Keep It Simple!

  When the ATtimy comes out of reset, it will:
  Delay for 500ms
  Measure the Thing Plus 3V3 rail
  Measure the USB 5V rail
  If USB power is present and 3V3 is not, the ATtiny will power on the USB2241 and go into "thumb drive" (SDIO) mode
  If 3V3 power is present and USB power is not, the ATtiny will go into Thing Plus / Arduino (SPI) mode
  If both power rails are present, the ATtiny will go into whichever mode is defined by defaultMode in EEPROM

  The user can command the ATtiny to power off the microSD card and go into deep sleep by sending command 0x03

  The user can change modes by sending command 0x04 or 0x05
  Command 0x04 will select Thing Plus / Arduino (SPI) mode
  Command 0x05 will select "thumb drive" (SDIO) mode

  Commands 0x04 and 0x05 can also be used to wake the ATtiny from deep sleep

  Simple diagnostics are output on the Serial TX pin at power up. (9600 baud)

  To Keep It Simple:
  The microSD SCK interrupt (INT0) is not used. (This could be used in the future to monitor microSD card activity in either mode)

  Supported I2C commands / registers are:
  0x00 : Set / Get the I2C Address
  0x01 : Get the Firmware Version
  0x02 : Set / Get the defaultMode: 0x00 = Thing Plus / Arduino (SPI) mode; 0x01 = "thumb drive" (SDIO) mode
  0x03 : Go into deep sleep (power down the microSD card too)
  0x04 : Wake from deep sleep (if required). Go into Thing Plus / Arduino (SPI) mode
  0x05 : Wake from deep sleep (if required). Go into "thumb drive" (SDIO) mode

*/

#include <Wire.h>

#include <EEPROM.h>

#include <avr/sleep.h> //Needed for sleep_mode
//#include <avr/power.h> //Needed for powering down perihperals such as the ADC
//#include <avr/wdt.h>

#include "Dual-Port_microSD_Shield_Constants.h"
#include "Dual-Port_microSD_Shield_EEPROM.h"

//Diagnostics
#define SERIAL_DIAGNOSTICS // Uncomment this line to enable diagnostics on serial at 9600 baud
//#define HEARTBEAT // Uncomment this line to output a heartbeat on serial

//Digital pins
const byte SPI_EN = 10; // SPI Enable: pull high to enable SPI buffer, pull low to disable
const byte MICROSD_CLK = 9; // MICROSD_CLK: could be used as an interrupt (INT0) to indicate SD card activity
const byte SDA_PIN = 6;
const byte SCL_PIN = 4;
const byte SDIO_EN = 3; // SDIO Enable: pull high to enable the USB2241 and its buffers, pull low to disable
const byte MICROSD_PWR_EN = 0; // microSD Power Enable: pull low to enable power for the microSD card, pull high or leave floating to disable

//Analog pins
const byte V_USB_DIV_2 = 8; // A8
const byte V_3V3_DIV_2 = 7; // A7

//Define the ON and OFF states for each pin
#define SPI_EN__ON   HIGH // SPI Enable: pull high to enable SPI buffer
#define SPI_EN__OFF  LOW  // SPI Enable: pull low to disable
#define SDIO_EN__ON   HIGH // SDIO Enable: pull high to enable the USB2241 and its buffers
#define SDIO_EN__OFF  LOW  // SDIO Enable: pull low to disable
#define MICROSD_PWR_EN__ON   LOW  // microSD Power Enable: pull low to enable power for the microSD card
#define MICROSD_PWR_EN__OFF  HIGH // microSD Power Enable: pull high or leave floating to disable

//Global variables
#define TINY_BUFFER_LENGTH 16
struct {
  volatile byte receiveEventRegister = (volatile byte)SFE_DUAL_SD_REGISTER_UNKNOWN; // Most recent receive event register address
  volatile byte receiveEventBuffer[TINY_BUFFER_LENGTH]; // byte array to store the data from the receive event
  volatile byte receiveEventLength = (volatile byte)0; // Indicates how many data bytes were received
} receiveEventData;
volatile bool sleepNow = (volatile bool)false;
volatile bool wdtSeen = (volatile bool)false; // Used for the heartbeat

void setup()
{
  //Just in case, make sure the system clock is set to 4MHz (8MHz divided by 2)
  cli(); // Disable interrupts
  CCP = 0xD8; // Write signature (0xD8) to the Configuration Change Register
  CLKPR = 1; //Set clock prescaler CLKPS bits to 1 == divide by 2
  sei(); // Enable interrupts

  // Make sure MICROSD_CLK (D9 / INT0 / XTAL2) is an input.
  // This seems critical!? Without this, badness happens when the USB2241 starts up in SDIO mode.
  pinMode(MICROSD_CLK, INPUT);

  // Make sure INT0 is disabled
  GIMSK = 0;

  // Disable the buffers, microSD card and the USB2241
  digitalWrite(SPI_EN, SPI_EN__OFF);
  pinMode(SPI_EN, OUTPUT);
  digitalWrite(SPI_EN, SPI_EN__OFF);
  
  digitalWrite(SDIO_EN, SDIO_EN__OFF);
  pinMode(SDIO_EN, OUTPUT);
  digitalWrite(SDIO_EN, SDIO_EN__OFF);

  digitalWrite(MICROSD_PWR_EN, MICROSD_PWR_EN__OFF);
  pinMode(MICROSD_PWR_EN, OUTPUT);
  digitalWrite(MICROSD_PWR_EN, MICROSD_PWR_EN__OFF);

#ifdef SERIAL_DIAGNOSTICS
  // Send diagnostics over serial
  Serial.begin(9600);
#endif

  enableWDT(); // Enable the WatchDog Timer (after Serial.begin)

  bool eepromReInit = false;
  if (!loadEepromSettings()) // Load the settings from eeprom
  {
    eepromReInit = true;
    initializeEepromSettings(); // Initialize them if required
  }

#ifdef SERIAL_DIAGNOSTICS
  // Send diagnostics over serial
  Serial.println(F("Dual-Port microSD Shield"));
  if (eepromReInit)
    Serial.println(F("Bad EEPROM data was detected on start-up. EEPROM reinitialized"));
  Serial.print(F("Firmware version "));
  Serial.print(eeprom_settings.firmwareVersion >> 4);
  Serial.print(F("."));
  Serial.println(eeprom_settings.firmwareVersion & 0x0F);
  Serial.print(F("I2C Address 0x"));
  Serial.println(eeprom_settings.i2cAddress, HEX);
  Serial.print(F("Default Mode "));
  if (eeprom_settings.defaultMode == SFE_DUAL_SD_MODE_SPI)
    Serial.println(F("SPI"));
  else
    Serial.println(F("SDIO"));
#endif

  //Delay for 500ms to let the voltage rails stabilize
  delay(500);

  //Read the USB and 3V3 voltages and decide which mode to go into
  float voltageUSB = readUSBvoltage();
  float voltage3V3 = read3V3voltage();

#ifdef SERIAL_DIAGNOSTICS
  Serial.print(F("Voltages: "));
  Serial.print(voltageUSB);
  Serial.print(F(","));
  Serial.println(voltage3V3);
#endif  

  //If USB power is present and 3V3 is not, the ATtiny will power on the USB2241 and go into "thumb drive" (SDIO) mode
  if ((voltageUSB > 4.0) && (voltage3V3 < 2.7))
  {
    sdioMode();
  }
  //If 3V3 power is present and USB power is not, the ATtiny will go into Thing Plus / Arduino (SPI) mode
  else if ((voltageUSB < 4.0) && (voltage3V3 > 2.7))
  {
    spiMode();
  }
  //If both power rails are present, the ATtiny will go into whichever mode is defined by EEPROM defaultMode
  else
  {
    if (eeprom_settings.defaultMode == SFE_DUAL_SD_MODE_SPI)
      spiMode();
    else
      sdioMode();
  }

  //Re-initialize the I2C register. Just in case...
  receiveEventData.receiveEventRegister = (volatile byte)SFE_DUAL_SD_REGISTER_UNKNOWN;
  receiveEventData.receiveEventLength = (volatile byte)0;
  sleepNow = (volatile bool)false;

  //Begin listening on I2C
  startI2C(true); // Skip Wire.end the first time around
}

void loop()
{
  //Check if a receive event has taken place
  if (receiveEventData.receiveEventLength > 0)
  {
    //Clear the event as early as possible so that the next event can arrive while (e.g.) the eeprom settings are being updated
    switch (receiveEventData.receiveEventRegister)
    {
      case SFE_DUAL_SD_REGISTER_I2C_ADDRESS: // Does the user want to change the I2C address?
        // receiveEventLength will be 1 if the user just wants to read the address
        if (receiveEventData.receiveEventLength == 2) // Data should be: register; new address
        {
          eeprom_settings.i2cAddress = receiveEventData.receiveEventBuffer[0] & 0x7F; // Update the I2C address in eeprom. Limit to 7 bits
          receiveEventData.receiveEventLength = (volatile byte)0; // Clear the event - ready for the next event
          saveEepromSettings(); // Update the address in eeprom
          startI2C(false); // Restart I2C comms
        }
        else
        {
          receiveEventData.receiveEventLength = (volatile byte)0; // Clear the event - ready for the next event
        }
        break;
      case SFE_DUAL_SD_REGISTER_FIRMWARE_VERSION: // Does the user want to read the firmware version?
        receiveEventData.receiveEventLength = (volatile byte)0; // Clear the event - ready for the next event
        break;
      case SFE_DUAL_SD_REGISTER_DEFAULT_MODE: // Does the user want to change the defaultMode?
        // receiveEventLength will be 1 if the user just wants to read the default mode
        if (receiveEventData.receiveEventLength == 2) // Data should be: register; new address
        {
          eeprom_settings.defaultMode = receiveEventData.receiveEventBuffer[0] & 0x01; // Update the defaultMode in eeprom. Limit to 1 bit
          receiveEventData.receiveEventLength = (volatile byte)0; // Clear the event - ready for the next event
          saveEepromSettings(); // Update the defaultMode in eeprom
        }
        else
        {
          receiveEventData.receiveEventLength = (volatile byte)0; // Clear the event - ready for the next event
        }
        break;
      case SFE_DUAL_SD_REGISTER_SLEEP: // Does the user want to sleep?
        receiveEventData.receiveEventRegister = (volatile byte)SFE_DUAL_SD_REGISTER_UNKNOWN; // Clear the receive event register - this one is write only
        if (receiveEventData.receiveEventLength == 1) // Should be a single byte
        {
          receiveEventData.receiveEventLength = (volatile byte)0; // Clear the event - ready for the next event
          sleepNow = true; // Go to sleep
        }
        else
        {
          receiveEventData.receiveEventLength = (volatile byte)0; // Clear the event - ready for the next event
        }
        break;
      case SFE_DUAL_SD_REGISTER_SPI_MODE: // Does the user want to wake (if required) and change mode?
        receiveEventData.receiveEventRegister = (volatile byte)SFE_DUAL_SD_REGISTER_UNKNOWN; // Clear the receive event register - this one is write only
        if (receiveEventData.receiveEventLength == 1) // Should be a single byte
        {
          receiveEventData.receiveEventLength = (volatile byte)0; // Clear the event - ready for the next event

          powerOffSD(); // Turn off the buffers and microSD card. They will already be off if the ATtiny was asleep

          delay(500);
          
          spiMode(); // Go into SPI mode
        }
        else
        {
          receiveEventData.receiveEventLength = (volatile byte)0; // Clear the event - ready for the next event
        }
        break;
      case SFE_DUAL_SD_REGISTER_SDIO_MODE: // Does the user want to wake (if required) and change mode?
        receiveEventData.receiveEventRegister = (volatile byte)SFE_DUAL_SD_REGISTER_UNKNOWN; // Clear the receive event register - this one is write only
        if (receiveEventData.receiveEventLength == 1) // Should be a single byte
        {
          receiveEventData.receiveEventLength = (volatile byte)0; // Clear the event - ready for the next event

          powerOffSD(); // Turn off the buffers and microSD card. They will already be off if the ATtiny was asleep

          delay(500);
          
          sdioMode(); // Go into SDIO mode
        }
        else
        {
          receiveEventData.receiveEventLength = (volatile byte)0; // Clear the event - ready for the next event
        }
        break;
      case SFE_DUAL_SD_REGISTER_UNKNOWN:
      default:
        receiveEventData.receiveEventLength = (volatile byte)0; // Clear the event - ready for the next event
        break;
    }    
  }

  // Sleep
  if (sleepNow)
  {
    powerOffSD(); // Turn off the buffers and microSD card

    disableWDT(); // Disable the WatchDog Timer so it does not wake the MCU

    byte adcsra = ADCSRA; //save ADCSRA (ADC control and status register A)
    ADCSRA &= ~_BV(ADEN); //disable ADC by clearing the ADEN bit
    
    byte acsr0a = ACSR0A; //save ACSR0A (Analog Comparator 0 control and status register)
    ACSR0A &= ~_BV(ACIE0); //disable AC0 interrupt
    ACSR0A |= _BV(ACD0); //disable ACO by setting the ACD0 bit
    
    byte acsr1a = ACSR1A; //save ACSR1A (Analog Comparator 1 control and status register)
    ACSR1A &= ~_BV(ACIE1); //disable AC1 interrupt
    ACSR1A |= _BV(ACD1); //disable AC1 by setting the ACD1 bit
    
    byte prr = PRR; // Save the power reduction register
    // Disable the ADC, USART1, SPI, Timer1 and Timer2
    // (Leave TWI, USART0 and Timer0 enabled)
    PRR |= _BV(PRADC) | _BV(PRUSART1) | _BV(PRSPI) | _BV(PRTIM1) | _BV(PRTIM2); 
    
    byte mcucr = MCUCR; // Save the MCU Control Register
    // Set Sleep Enable (SE=1), Power-down Sleep Mode (SM1=1, SM0=0), INT0 Change (ISC01=0, ISC00=1)
    MCUCR = _BV(SE) | _BV(SM1) | _BV(ISC00);

    sleep_cpu(); //go to sleep
    
    MCUCR = mcucr; // Restore the MCU control register
    PRR = prr; // Restore the power reduction register
    ACSR1A = acsr1a; // Restore ACSR1A    
    ACSR0A = acsr0a; // Restore ACSR0A    
    ADCSRA = adcsra; //Restore ADCSRA

    enableWDT(); // Enable the WatchDog Timer

    sleepNow = (volatile bool)false; // Clear sleepNow

    //startI2C(false); // Restart I2C comms. Just in case
  }

#if defined(SERIAL_DIAGNOSTICS) && defined(HEARTBEAT)
  if (wdtSeen)
  {
    Serial.print(F("."));
    wdtSeen = (volatile bool)false;
  }
#endif
}

//Begin listening on I2C bus as I2C peripheral using the global I2C_ADDRESS
void startI2C(bool skipWireEnd)
{
  if (skipWireEnd == false)
    Wire.end(); //Before we can change addresses we need to stop

  Wire.begin(eeprom_settings.i2cAddress); //Do the Wire.begin using the defined I2C_ADDRESS

  //The connections to the interrupts are severed when a Wire.begin occurs. So re-declare them.
  Wire.onReceive(receiveEvent);
  Wire.onRequest(requestEvent);
}

//Measure the USB voltage using VCC as the reference
float readUSBvoltage()
{
  analogReference(SFE_DUAL_SD_ADC_REFERENCE_VCC); //Use VCC as the reference
  
  // "The first ADC conversion result after switching reference voltage source may be inaccurate,
  //  and the user is advised to discard this result."
  analogRead(0x80 | V_USB_DIV_2); //Read the analog voltage and discard the result
  
  uint16_t result = 0;
  for (byte x = 0; x < 8; x++)
  {
    result += analogRead(0x80 | V_USB_DIV_2); //Read the analog voltage
    noIntDelay(1);
  }
  
  float voltage = (float)(result >> 3); // Divide result by 8. Convert to float
  voltage /= 1023.0; // Convert to fraction of VCC
  voltage *= 3.3; // Convert to voltage (multiply by VCC)
  voltage *= 2.0; // Correct for the voltage divider
  
  return (voltage);
}

//Measure the 3V3 voltage using VCC as the reference
float read3V3voltage()
{
  analogReference(SFE_DUAL_SD_ADC_REFERENCE_VCC); //Use VCC as the reference
  
  // "The first ADC conversion result after switching reference voltage source may be inaccurate,
  //  and the user is advised to discard this result."
  analogRead(0x80 | V_3V3_DIV_2); //Read the analog voltage and discard the result
  
  uint16_t result = 0;
  for (byte x = 0; x < 8; x++)
  {
    result += analogRead(0x80 | V_3V3_DIV_2); //Read the analog voltage
    noIntDelay(1);
  }
  
  float voltage = (float)(result >> 3); // Divide result by 8. Convert to float
  voltage /= 1023.0; // Convert to fraction of VCC
  voltage *= 3.3; // Convert to voltage (multiply by VCC)
  voltage *= 2.0; // Correct for the voltage divider
  
  return (voltage);
}

//Configure the pins for Thing Plus / Arduino (SPI) mode
void spiMode()
{
  digitalWrite(MICROSD_PWR_EN, MICROSD_PWR_EN__ON); // Enable power for the microSD card
  delay(250);
  digitalWrite(SDIO_EN, SDIO_EN__OFF); // Disable the USB2241 and the SDIO buffers
  delay(100);
  digitalWrite(SPI_EN, SPI_EN__ON); // Enable the SPI buffer
  delay(100);
}

//Configure the pins for "thumb drive" (SDIO) mode
void sdioMode()
{
  digitalWrite(MICROSD_PWR_EN, MICROSD_PWR_EN__ON); // Enable power for the microSD card
  delay(250);
  digitalWrite(SPI_EN, SPI_EN__OFF); // Disable the SPI buffer
  delay(100);
  digitalWrite(SDIO_EN, SDIO_EN__ON); // Enable the USB2241 and the SDIO buffers
  delay(100);
}

//Turn off the buffers and microSD card
void powerOffSD()
{
  digitalWrite(SDIO_EN, SDIO_EN__OFF); // Disable the USB2241 and the SDIO buffers
  delay(50);
  digitalWrite(SPI_EN, SPI_EN__OFF); // Disable the SPI buffer
  delay(50);
  // Disable power for the microSD card
  pinMode(MICROSD_PWR_EN, INPUT_PULLUP); // Charge the FET Gate capacitance
  delay(10);
  digitalWrite(MICROSD_PWR_EN, MICROSD_PWR_EN__OFF); // Now drive the Gate high
  pinMode(MICROSD_PWR_EN, OUTPUT);
  digitalWrite(MICROSD_PWR_EN, MICROSD_PWR_EN__OFF);
  delay(40);
}

// ISR for watchdog timer
ISR(WDT_vect) {
  // To avoid the Watchdog Reset, WDIE must be set after each interrupt.
  WDTCSR |= (1 << WDIE); // Re-enable the WDT interrupt. Don't disable the WDT. Don't change the prescaler.
  wdtSeen = (volatile bool)true;
}

// Disable the WDT
void disableWDT()
{
  cli(); // Disable interrupts
  CCP = 0xD8; // Write signature (0xD8) to the Configuration Change Register
  // Within the next four clock cycles, write a logic 0 to WDE.
  WDTCSR = 0x00; // Disable the Watchdog and the interrupt and clear the prescaler.
  sei(); // Enable interrupts
}

// Enable the WDT:
// Enable both the Watchdog Timeout Interrupt (WDIE) _and_ the Watchdog itself (WDE)
// The WDT will generate an interrupt after a time-out of prescaler cycles
// The WDIE bit needs to be (re)set by the ISR to prevent the WDT from resetting the CPU at the next time-out
// Setting the prescaler to 0x05 produces a 500ms timeout
void enableWDT()
{
  cli(); // Disable interrupts
  // Make wdtBits volatile to avoid the compiled code for the "WDTCSR = wdtBits"
  //  being too slow and not meeting the "within four clock cycles" requirement.
  volatile byte wdtBits = (1 << WDIE) | (1 << WDE) | 0x05; // WDT Interrupt Enable OR'd with WDE and the prescaler bits
  CCP = 0xD8; // Write signature (0xD8) to the Configuration Change Register
  WDTCSR = wdtBits; // Enable the WDT interrupt, WDT and set the prescaler
  sei(); // Enable interrupts
}

//Software delay. Does not rely on internal timers.
void noIntDelay(byte amount)
{
  for (volatile byte y = 0 ; y < amount ; y++)
  {
    //ATtiny84 at 4MHz
    for (volatile unsigned int x = 0 ; x < 202 ; x++) //1ms at 4MHz
    {
      __asm__("nop\n\t");
    }
  }
}

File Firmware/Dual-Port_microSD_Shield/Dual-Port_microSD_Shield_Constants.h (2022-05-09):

// Dual-Port microSD Shield EEPROM constants

//Define the firmware version
#define SFE_DUAL_SD_FIRMWARE_VERSION            0x11 // v1.1

//Define the ATtiny841's default I2C address (unshifted)
#define SFE_DUAL_SD_DEFAULT_I2C_ADDRESS         0x51

//Define the modes
#define SFE_DUAL_SD_MODE_SPI                    0x00 // Thing Plus / Arduino (SPI) mode
#define SFE_DUAL_SD_MODE_SDIO                   0x01 // "thumb drive" (SDIO) mode

//Define the firmware register addresses:
#define SFE_DUAL_SD_REGISTER_I2C_ADDRESS        0x00 // byte     Read/Write: Stored in EEPROM
#define SFE_DUAL_SD_REGISTER_FIRMWARE_VERSION   0x01 // byte     Read only
#define SFE_DUAL_SD_REGISTER_DEFAULT_MODE       0x02 // byte     Read/Write: Stored in EEPROM
#define SFE_DUAL_SD_REGISTER_SLEEP              0x03 // Virtual write-only register: Go into deep sleep
#define SFE_DUAL_SD_REGISTER_SPI_MODE           0x04 // Virtual write-only register: Wake from deep sleep (if required) and go into Thing Plus / Arduino (SPI) mode
#define SFE_DUAL_SD_REGISTER_SDIO_MODE          0x05 // Virtual write-only register: Wake from deep sleep (if required) and go into "thumb drive" (SDIO) mode
#define SFE_DUAL_SD_REGISTER_UNKNOWN            0xFF

//ADC Reference (with AREF disconnected)
#define SFE_DUAL_SD_ADC_REFERENCE_VCC           0
#define SFE_DUAL_SD_ADC_REFERENCE_1V1           1
#define SFE_DUAL_SD_ADC_REFERENCE_2V2           2
#define SFE_DUAL_SD_ADC_REFERENCE_4V096         3

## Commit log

2021-12-21 Changed to 4-layer PCB. Routed. Add Schematic.pdf.
    [Dual-Port_microSD_Shield_USB2241.brd]
2021-12-22 Add silk. Replace xtal caps with calculated values. Finishing touches...
    [Dual-Port_microSD_Shield_USB2241.brd, Dual-Port_microSD_Shield_USB2241.sch]
2021-12-23 Corrected 74HC4066 footprint. Swapped U4 and U5.
    [Dual-Port_microSD_Shield_USB2241.brd, Dual-Port_microSD_Shield_USB2241.sch]
2021-12-24 Add footprint for optional I2C EEPROM
    [Dual-Port_microSD_Shield_USB2241.brd, Dual-Port_microSD_Shield_USB2241.sch]
2022-01-20 Final Eagle files for Proto
    [Dual-Port_Logging_Shield.brd, Dual-Port_Logging_Shield.sch]
2022-01-26 Updates post proto review
    [Dual-Port_Logging_Shield.brd, Dual-Port_Logging_Shield.sch]
2022-01-27 Nudged the silk labels
    [Dual-Port_Logging_Shield.brd]
2022-01-27 Add Gerbers
2022-03-04 Update firmware: clear the I2C event as early as possible, ready for the next
2022-03-04 Add v10 hardware files
    [Dual-Port_Logging_Shield-Panel.GBL, Dual-Port_Logging_Shield-Panel.GBO, Dual-Port_Logging_Shield-Panel.GBP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]
2022-03-14 Updated hardware files after REDS Review
    [Dual-Port_Logging_Shield-Panel.GBL, Dual-Port_Logging_Shield-Panel.GBO, Dual-Port_Logging_Shield-Panel.GBP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]
2022-03-16 Update firmware after REDS code review. Move examples to Arduino Library.
2022-05-10 PCB v1.1
    [Dual-Port_Logging_Shield-Panel.brd, Dual-Port_Logging_Shield.brd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]

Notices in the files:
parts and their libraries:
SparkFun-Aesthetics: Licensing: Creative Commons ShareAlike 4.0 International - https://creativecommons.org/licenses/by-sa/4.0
